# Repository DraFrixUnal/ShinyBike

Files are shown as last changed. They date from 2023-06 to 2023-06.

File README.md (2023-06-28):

# Shiny Bike

Dispositivo que busca iluminar y señalizar a las bicicletas.

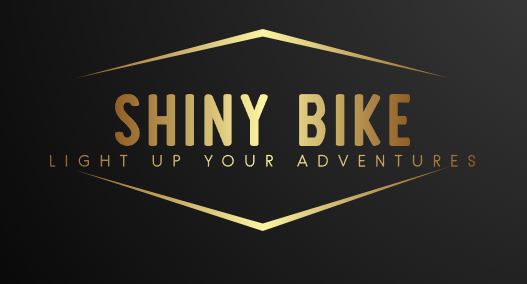
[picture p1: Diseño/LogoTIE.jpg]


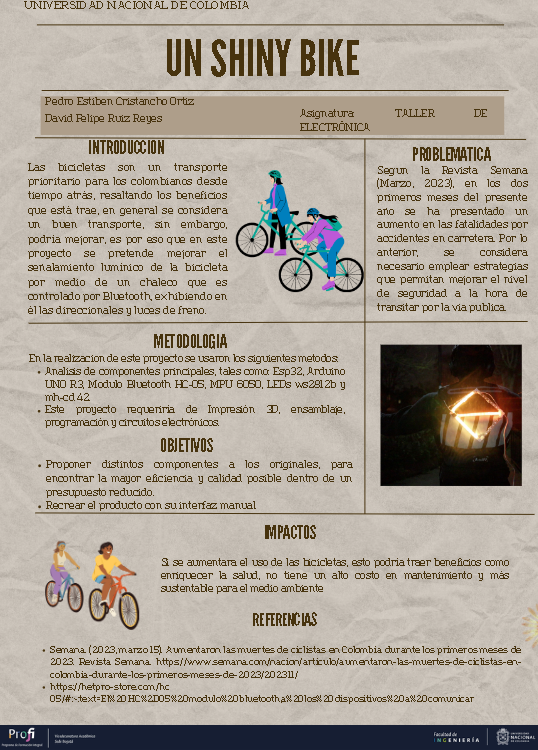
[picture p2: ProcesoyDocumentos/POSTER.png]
Poster


## Descripcion

Este dispositivo busca que los ciclistas puedan señalizar a traves de luces su recorrido en las calles (direccionales, frenado, parqueo). El dispositivo se divide en dos partes, la primera la cual es un control remoto permite al usuario emitir comandos manueales y comandos automaticos para el seña.amiento, segun que comando dicte se enviaran datos via Bluetooth a la segunda parte, la cual se encarga de iluminar los led RGB Ws2812b.

## Objetivos

- Desarrollar un dispositivo que sea capaz de iluminar y señalizar de forma remota a cualquier bicicleta.
- Desarrollar los esquematicos, PCB, diseños y codigos que permitan alcanzar el dispositivo y un buen aprendizaje

## Alcance

Todos los ciclistas que quieran iluminar sus aventuras en la calle.

## Planeación 

### Diagrama de Flujo

Aqui se establecio oficialmente las funciones y las interacciones del dispositivo.

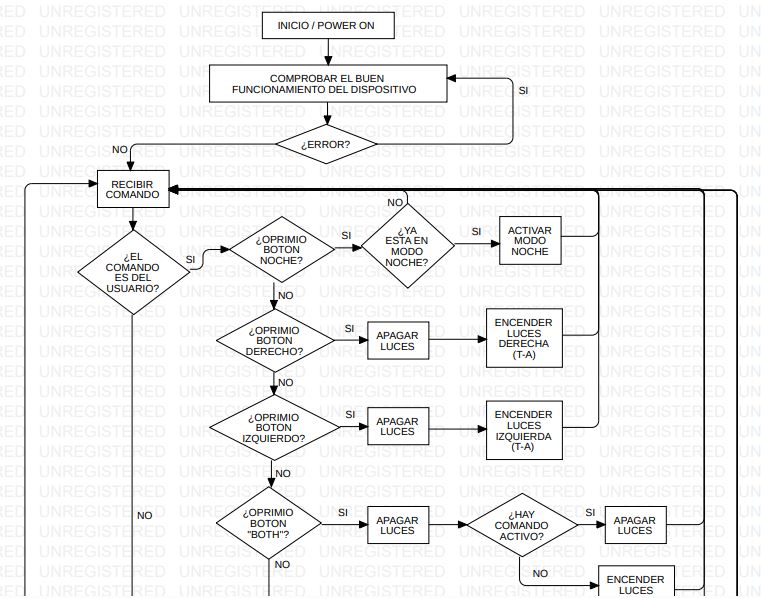
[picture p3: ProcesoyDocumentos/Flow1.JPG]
Flow1

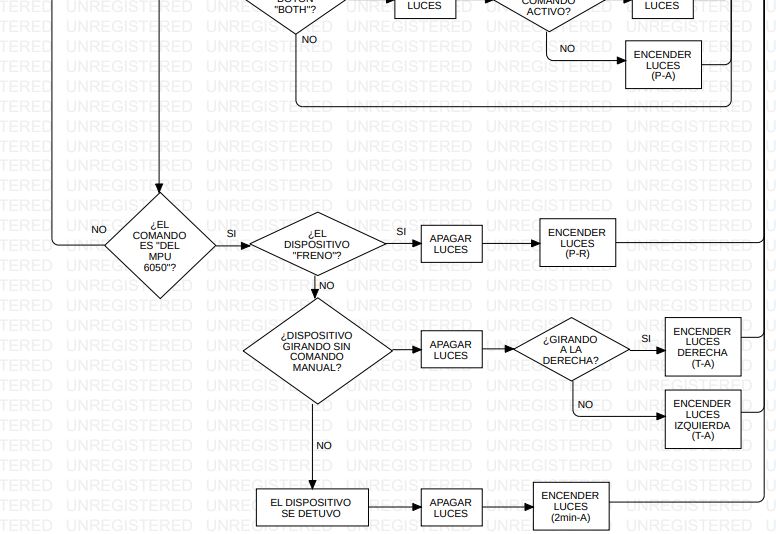
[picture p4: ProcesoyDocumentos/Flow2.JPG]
Flow2


### Diagrama de Cajas Negras

Aqui se establecieron las principales tecnologias.

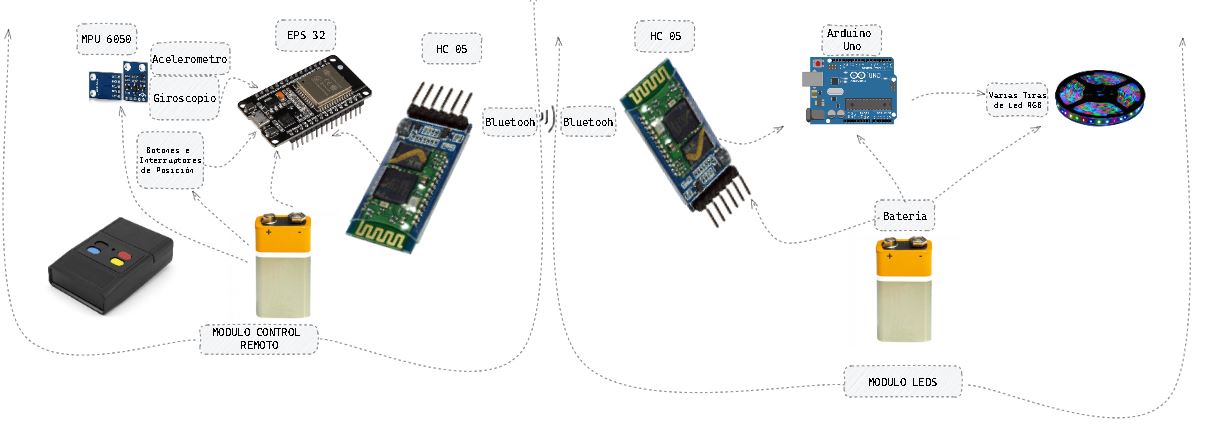
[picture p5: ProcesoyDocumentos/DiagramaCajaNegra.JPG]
DCN


# Diseño

En esta sección, se empieza diseñar y construir la parte electronica del dispositivo, con lo cual se diseñaron los esquematicos y las PCB.

## Esquematicos

Esquematico Control Remoto
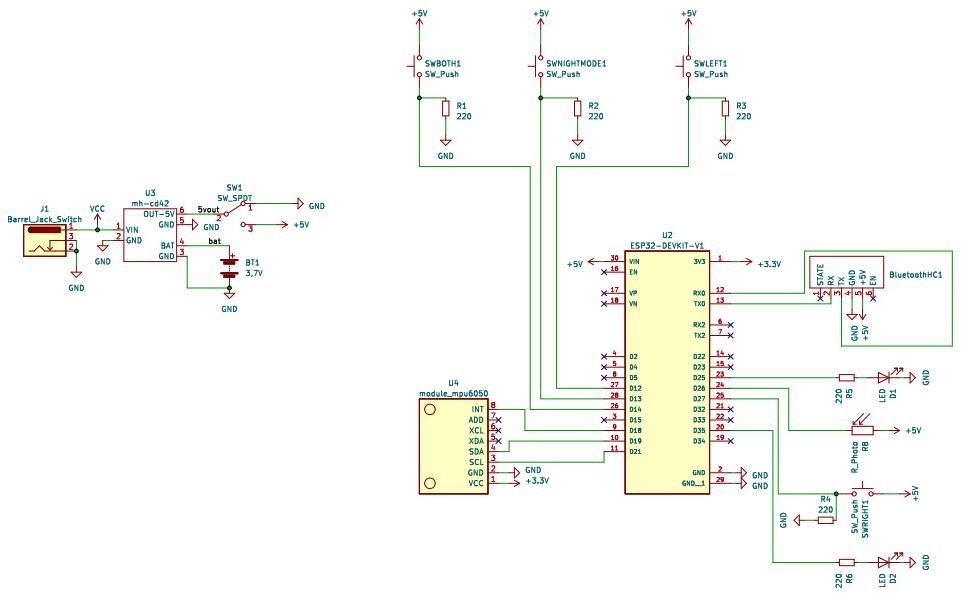
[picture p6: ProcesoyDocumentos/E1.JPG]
E1

Esquematico Luces
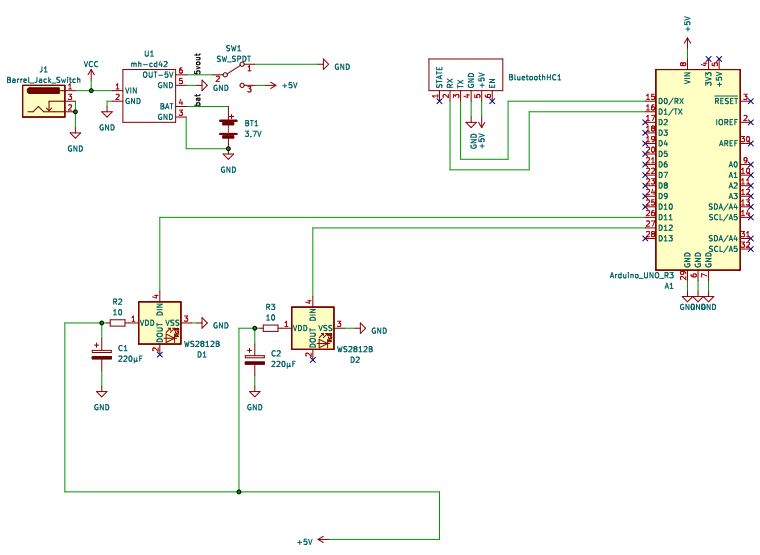
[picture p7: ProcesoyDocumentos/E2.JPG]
E2


## PCB

PCB del Control Remoto

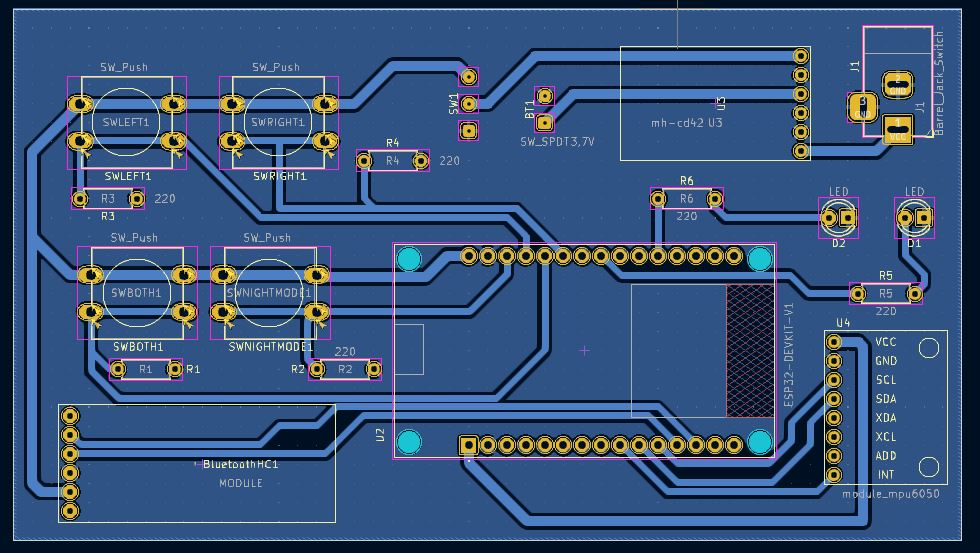
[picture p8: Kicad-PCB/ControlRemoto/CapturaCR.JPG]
PCB1

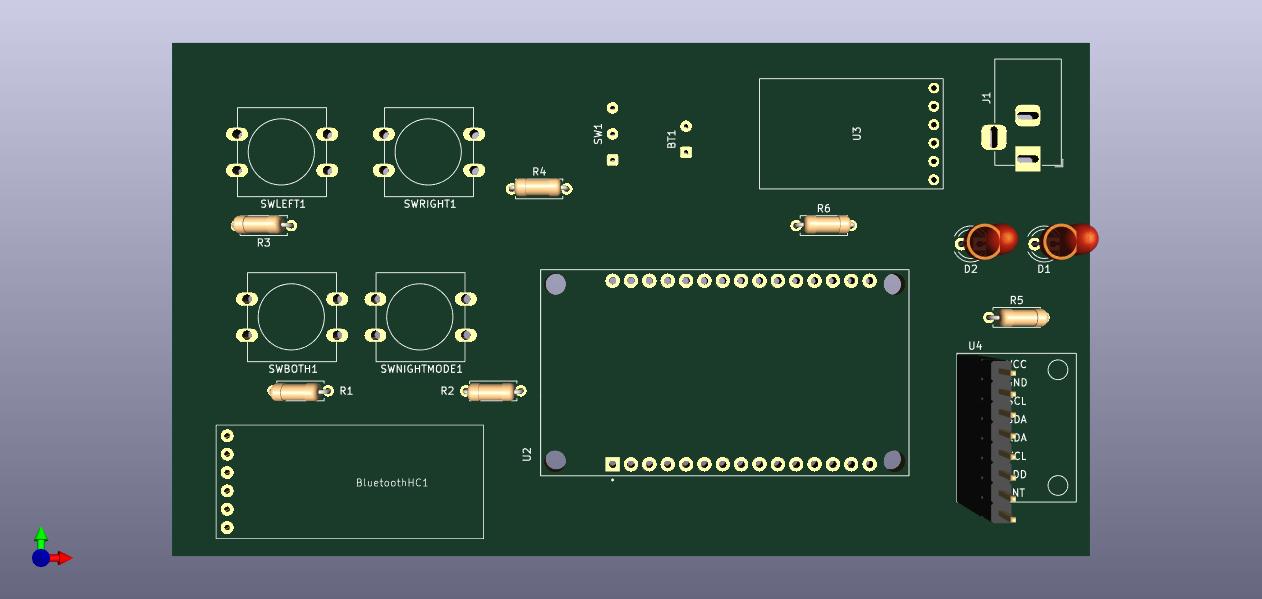
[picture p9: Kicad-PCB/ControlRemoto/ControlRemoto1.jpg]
PCB11

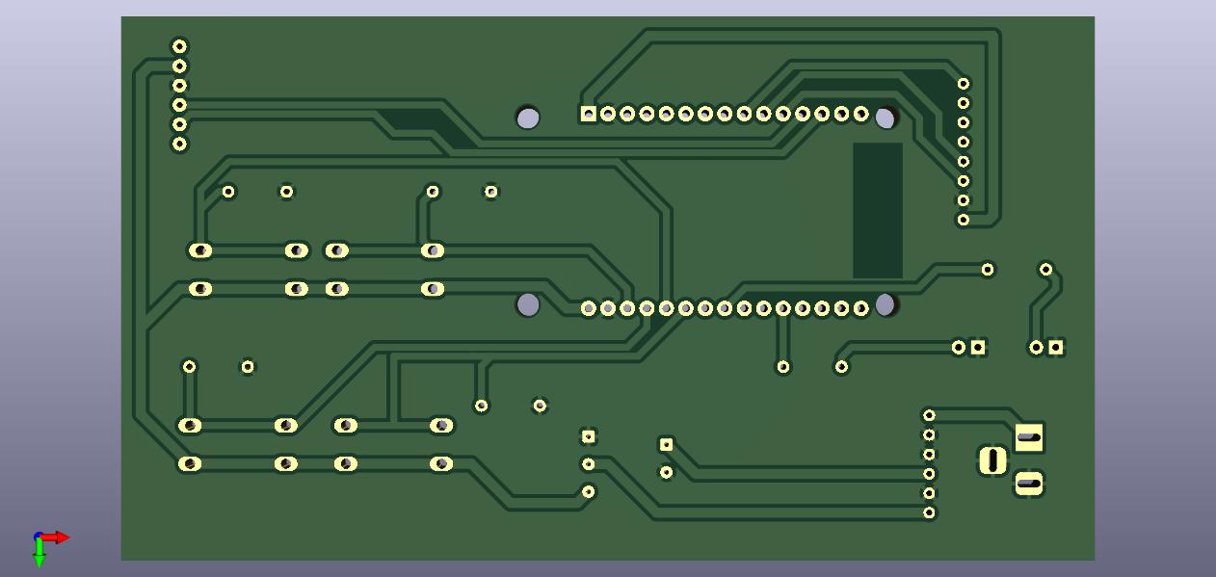
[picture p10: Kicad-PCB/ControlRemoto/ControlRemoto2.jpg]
PCB111


PCB de apartado de Luces

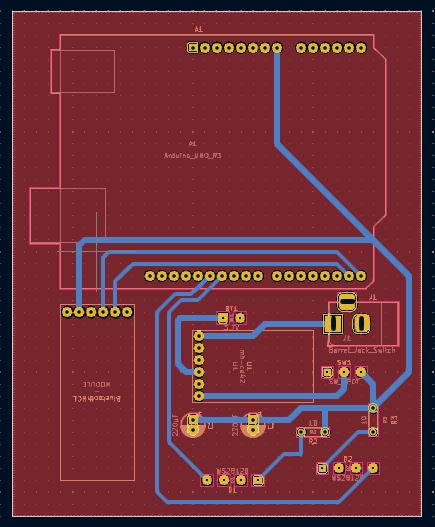
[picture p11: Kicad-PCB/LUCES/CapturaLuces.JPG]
PCB2

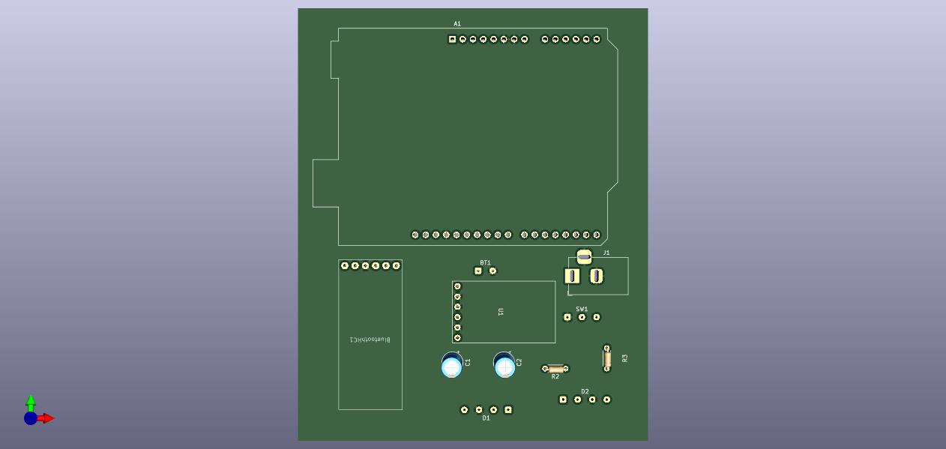
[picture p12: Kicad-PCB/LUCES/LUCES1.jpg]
PCB22

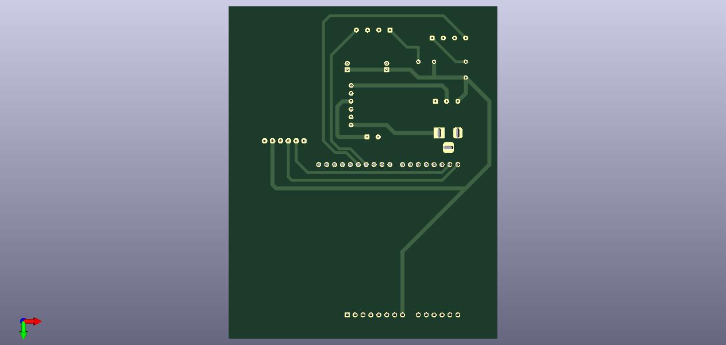
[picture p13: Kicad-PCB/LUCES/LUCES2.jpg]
PCB222


# Prueba y Trabajo hecho

Aqui se realizaron pruebas en ProtoBoard para corroborar el funcionamiento del codigo y construir el dispositivo final.

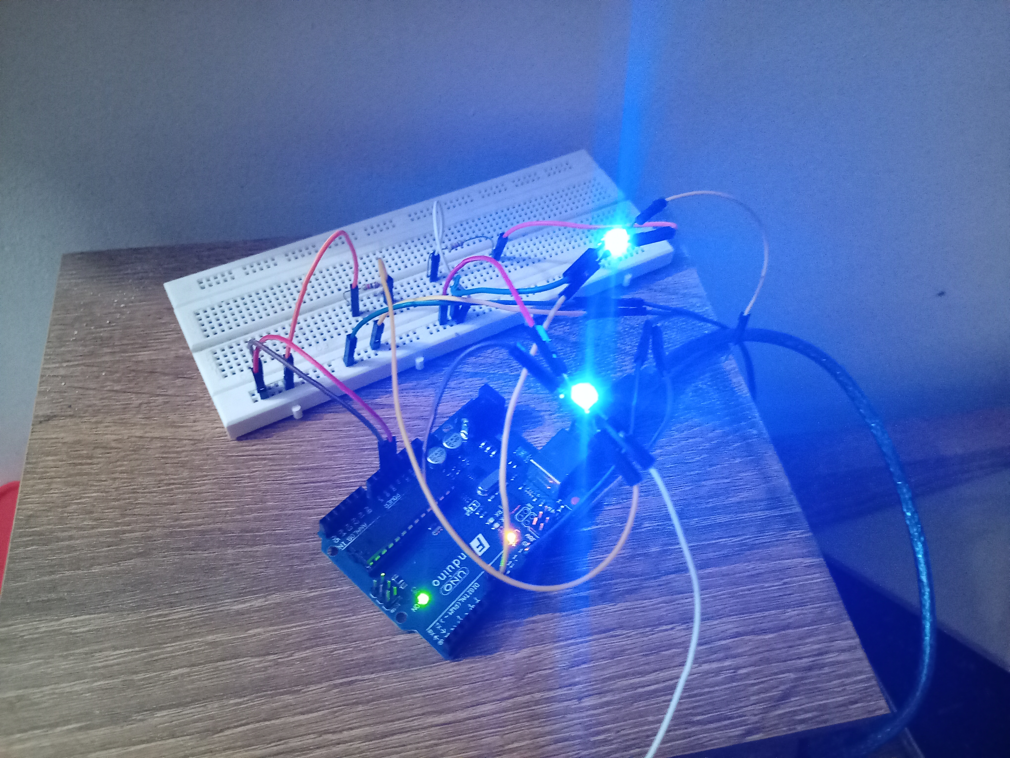
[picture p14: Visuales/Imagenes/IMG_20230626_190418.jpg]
T1


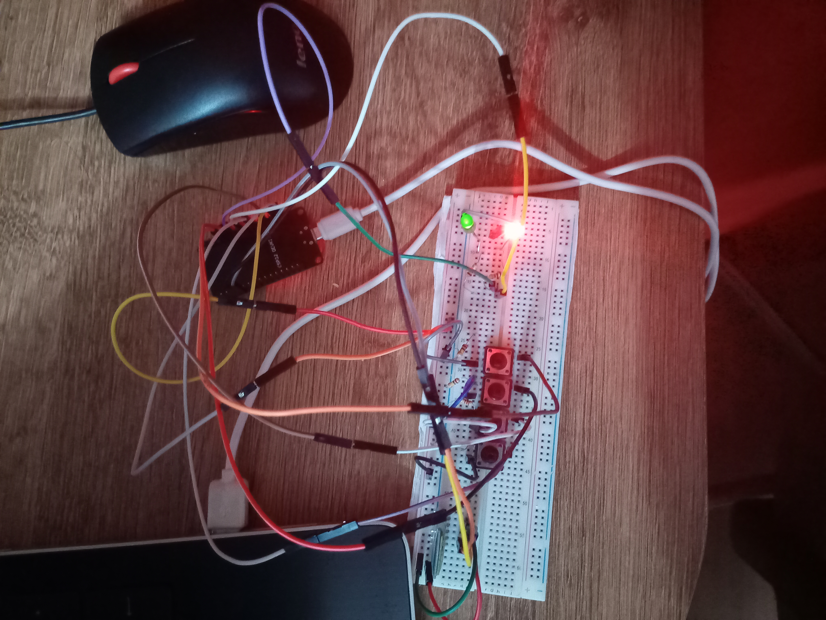
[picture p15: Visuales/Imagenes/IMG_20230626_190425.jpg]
T2


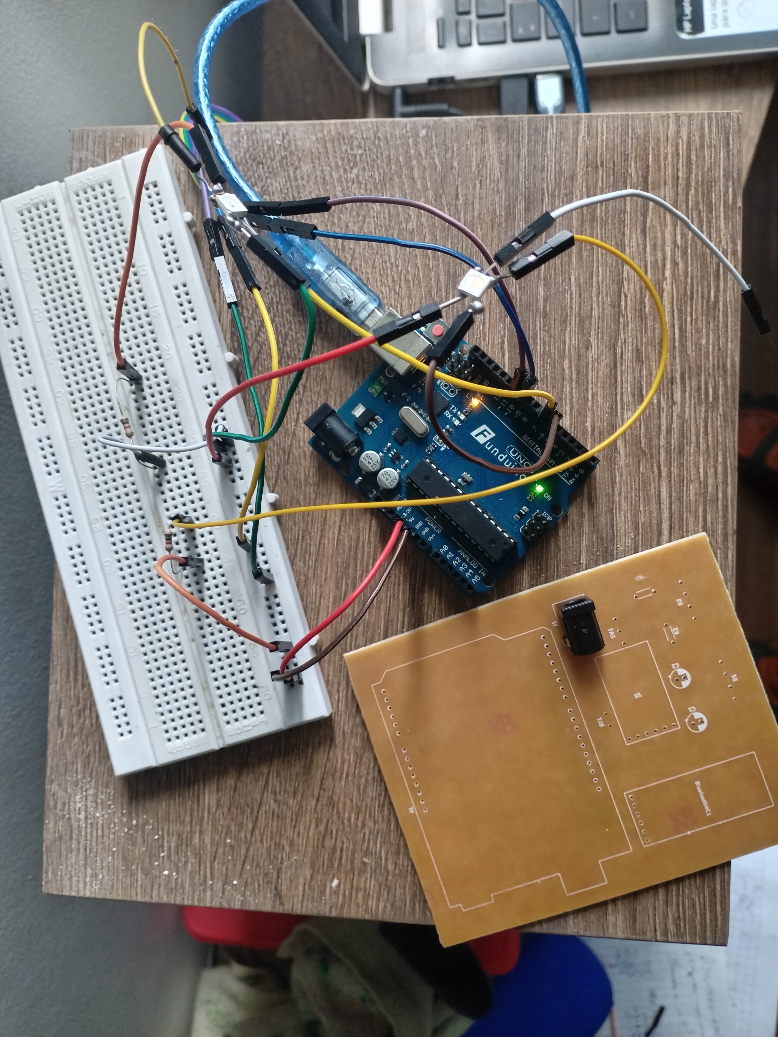
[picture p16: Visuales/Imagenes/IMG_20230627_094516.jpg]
T3


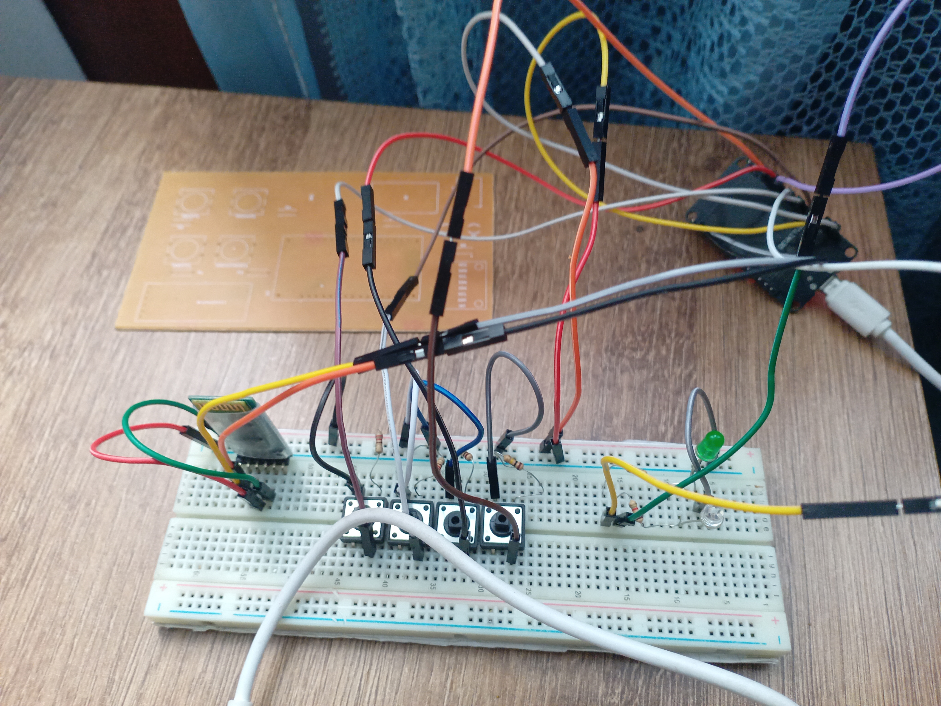
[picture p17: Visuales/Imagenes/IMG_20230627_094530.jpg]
T4


T5

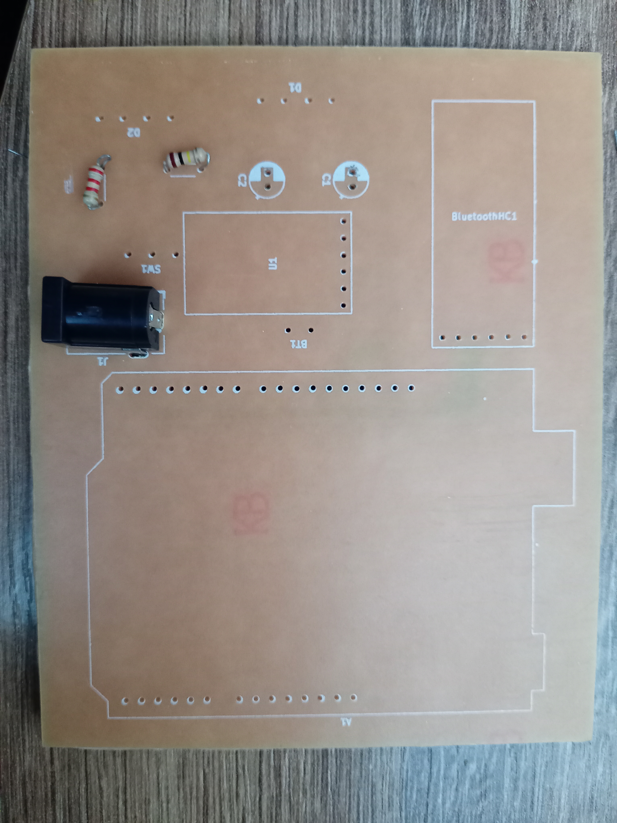
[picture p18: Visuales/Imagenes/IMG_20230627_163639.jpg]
T6


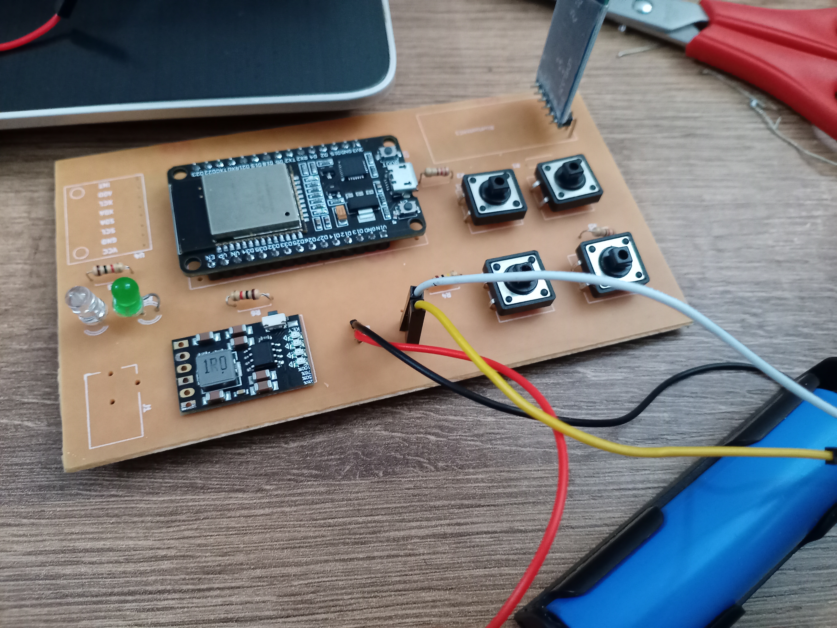
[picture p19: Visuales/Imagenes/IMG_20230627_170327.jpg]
T7


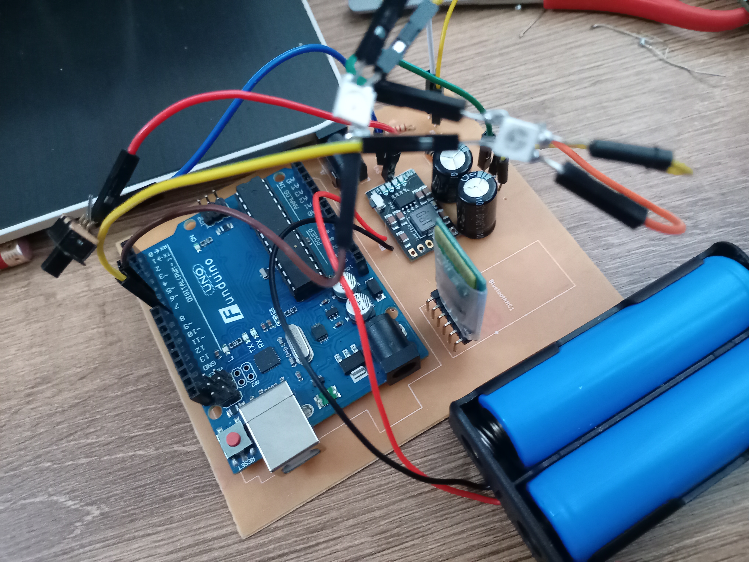
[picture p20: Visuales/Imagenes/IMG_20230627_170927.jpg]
T8


## Videos

Links de los videos:
 - Dispositivo funcionamiento [Vdf](https://youtu.be/l_CRdRnh4ok)
 - Explicacion Bluetooth [Veb](https://youtu.be/JUIpYABRpQY)
 - Videos de los problemas [Vp1](https://youtu.be/4-EyFK3v-QM),[Vp2](https://youtube.com/shorts/PcfQB73DB2A?feature=share),[Vp3](https://youtu.be/3R93eb1QBnk)

## Muchas gracias por su visita

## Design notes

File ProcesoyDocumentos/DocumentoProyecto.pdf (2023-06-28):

PROCESO DEL PROYECTO

DEFINICIÓN Y PLANEACIÓN DEL PROYECTO

Inicialmente nos planteamos tres alternativas, dos de estas eran de entretenimiento o decoración (característica que los descarto):

1. Un cubo de Leds RGB dinámicos y programables.
2. Un reloj de cartas - Calendario de cartas.
3. Dispositivo para dar señalamiento lumínico a las bicicletas.

Si estás aquí sabrás que escogimos la tercera opción y empezamos con la determinación de las funcionalidades. Para esto realmente se mantuvo una pequeña conversación ya que estas funcionalidades eran bastantes obvias, siendo las siguientes:

- Poner iluminar la dirección a tomar (derecha o izquierda).
- Poner señalar un próximo detenimiento o parqueo.
- Poder señalar el proceso de frenado.
- Cuando es de noche, se debe de tener iluminación permanente respetando las funcionalidades previas.

También por tema de presupuesto se dejo que las funcionalidades quedaran en “iluminación”, ya que el dispositivo como se mencionara posteriormente podría tener un sistema de sonido, un sistema que mida distancias o un sistema GPS.

Diagrama de Caja Negra

Ya con las funcionalidades establecidas se empezó a establecer la tecnología a utilizar. Para esto se utilizo el diagrama de caja negra el cual es muy intuitivo y dinámico, teniendo el siguiente resultado:

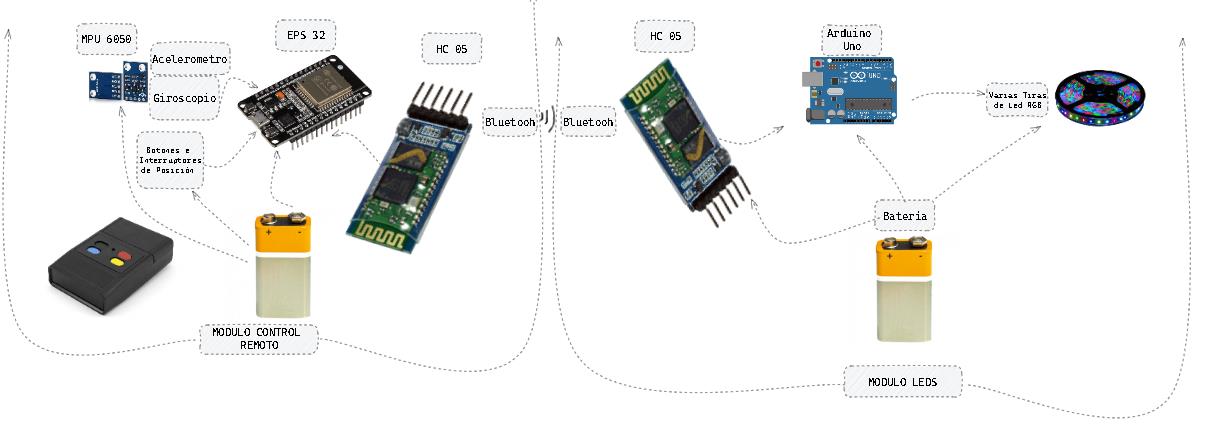
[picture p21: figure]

Este diagrama se divide en dos partes, la parte del Control Remoto y la parta de las Luces (De aquí en adelante cada parte se llamará correspondientemente a lo dicho).

El Control Remoto posee un esp32 DEVKIT DOIT v1 como cerebro, una batería (18650 de 3,7V) como alimentación, un MPU 6050 para automatizar algunas señales y el HC-05 para la conexión Bluetooth con Luces, el cual a su vez contiene un hc.05, un Arduino UNO como cerebro, dos baterías como alimentación y una conexión a las tiras LED de iluminación.

Ahora ampliando lo dicho, queremos empezar con la siguiente pregunta: ¿Por qué se escogieron estas tecnologías? Iniciemos por el HC-05, este dispositivo nos permite generar una conexión Bluetooth entre ellos y además nos permite controlar las direcciones entre los módulos, contraseñas, nombres, controlar si es un Maestro o Esclavo (Si es host o no), etc. Con esto conseguimos una conexión entre partes remotas de un mismo dispositivo de manera segura, rápida y confiable. Sobre el MPU 6050 es muy poco lo que toca mencionar en este documento, este dispositivo es muy versátil a la hora de medir alteraciones en la velocidad lineal y en la velocidad angular, siendo perfecto para medir los cambios que pueden presentarse a la hora de usar una bicicleta o cualquier vehículo (Se recomienda leer sobre este dispositivo en internet). Para escoger el esp32 y el Arduino fue mas complicado el camino ya que inicialmente teníamos que el MPU 6050 funciona mejor bajo 3,3V mientras que el resto de los circuitos trabajaban a 5V, se sumaba el hecho de necesitar trabajar en el lenguaje C++ para el manejo de librerías próximas a escoger, junto a la necesidad de escoger entre Wi-Fi y Bluetooth en la interconexión (el primer componente a escoger de cada parte fueron los cerebros), el pequeño espacio que debían tener la PCB fututas y el tema del presupuesto. Pero con una leve investigación el esp32 era la elección más acertada ya que cumplía todas las características e incluía las formas de interconexión mencionadas (se escogió Bluetooth por la economía del HC-05 y no se usó el propio del esp32 por temas de seguridad), ¿pero entonces, donde aparece en juego el Arduino? El Arduino aparece por la imposibilidad de conseguir el segundo esp32, ya que los envíos estaban ciertamente caros y el Arduino ya se tenía en posesión antes de iniciado el proyecto. La única desventaja que esto representa es el tamaño de la placa.

Sobre las tiras LED RGB, se escogieron los ws2812b, ya que presentaban una alta gama de colores, las librerías son sencillas de utilizar, algunas webs aseguraban que eran aprueba de agua e iluminan bastante. Por economía se compraron los LED en si y no las cintas, ya que nuevamente los envíos son excesivamente caros en Colombia (el metro de la cinta es barato en contraste). Por último, en la parte de alimentación tenemos a las baterías 18650 de 3,7V que se escogieron por ser tanto recargables como duraderos (el dispositivo puede pasar bastante tiempo sin cargar), para cargar dichas baterías se usaron puertos Jack y módulos MD-CH42 que permiten hacer el proceso de carga-descarga de baterías dando 5V constantes al circuito.

Diagrama de flujo – Costos

Invitamos a ver o descargar los archivos adjuntos a este proyecto, ya que lo que se mencionara aquí son mínimos detalles.

Sobre el diagrama de flujo cabe resaltar que existen funcionalidades prioritarias, como los es el frenado y por esto mismo en el flujo a la hora de existir una desaceleración todas las otras funciones quedan bloqueadas.

Sobre los costos se ha de resaltar que las compras fueron hibridas y que el presupuesto estaba alrededor de los $200.000

Con esto la planeación había acabado y entramos a la producción.

ESQUEMATICOS, CODIGO Y PCB

Para esta parte se usaron dos Software, KiCad para la creación de los esquemáticos y las PCB, y Arduino IDE para el código.

Empezando por lo esquemáticos, estos iniciaron con la búsqueda de las “imágenes” de cada componente para poder generar las conexiones, anotación y correcciones correspondientes. Este proceso fue el mas laborioso realmente, siendo sorprendente el hecho de que nos tocara hacer los esquemas para el HC-05 t el MPU-6050 por mano propia (usando KiCad), pero fue una experiencia valiosa. Al final se generaron los siguientes esquemáticos:

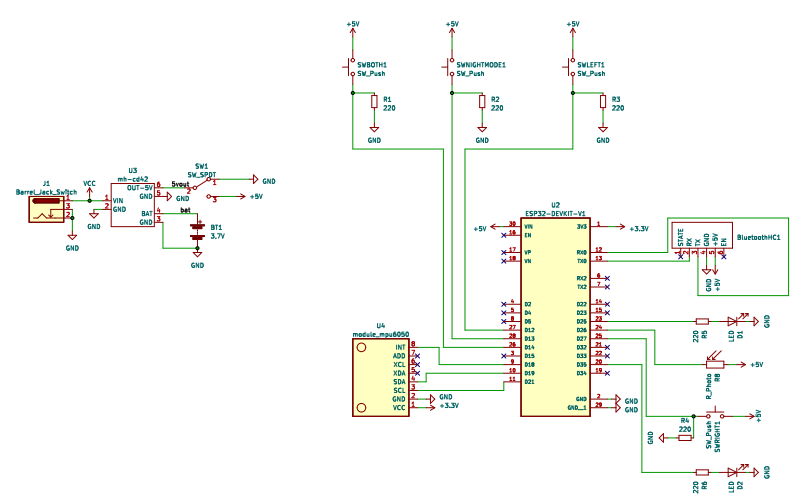
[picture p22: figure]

Esquemático Control Remoto

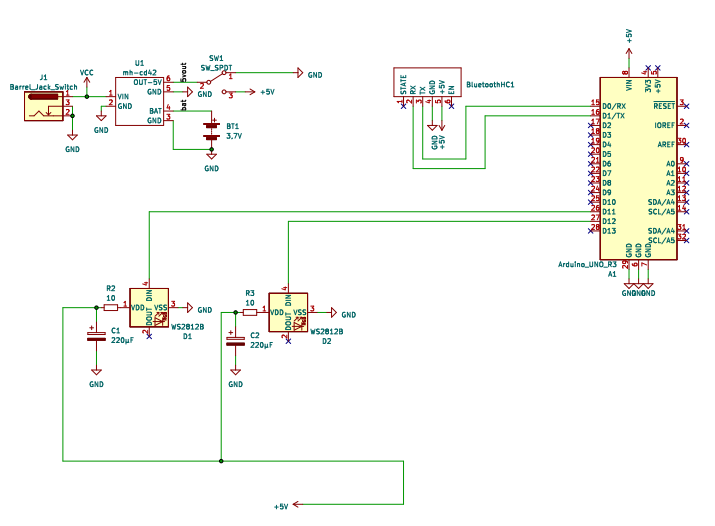
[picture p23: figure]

Esquemático Luces

Ya con los esquemáticos hechos asignamos las huellas (footprints) de cada componente, siendo para varias de ellas (como los ws2812b) simples “puntos de conexión”. Cabe aclarar que también toco realizar algunos footprints propios.

Después de esto seguía la creación de las dos PCB, pero como ya se tenía la mayoría hecho gracias a los esquemáticos, solo todo ordenar los componentes y realizar las conexiones (diferenciando los anchos de pista según el voltaje y la función de cada una, por ejemplo, las pistas de señal requieren menos grosor) y creando un campo GND. El resultado fue el siguiente:

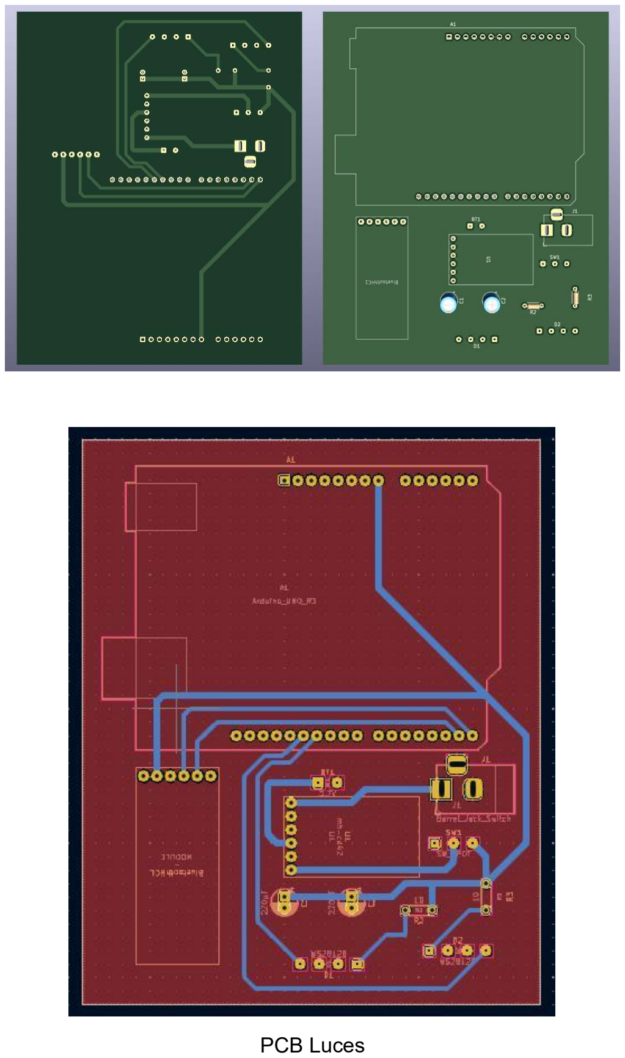
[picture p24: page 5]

PCB Luces

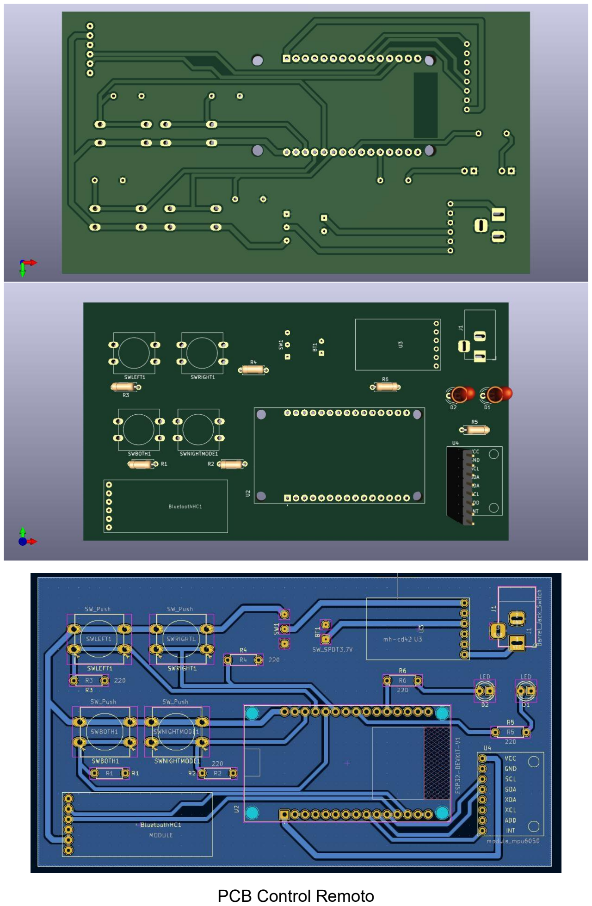
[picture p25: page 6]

PCB Control Remoto

Con todo listo se empezó el desarrollo del código. Primero cabe aclarar que la parte de decir que LED encendía o como se enviaba información a través del Serial se deja a disposición del lector, por lo sencillo que ha de ser el código. Por lo que solo hablaremos de lo importante.

Primero se configuraron lo HC-05, para estos se conectaron los módulos tanto al esp32 como al Arduino (igual que en el esquemático, pero mientras se conecta el 5V de los módulos se ha de oprimir el botón que estos poseen, así entran en modo de configuración) y se empezó una conexión con el Monitor Serial a 9600 baudios, después se inició la conexión con los módulos a 38400 baudios, permitiendo utilizar los comando AT. Estos comandos permiten conocer los datos de los HC-05 como el nombre o la contraseña y a su vez los permite cambiar. La ecuación es esta, para conocer un dato se colocar AT+(NAME o PSWD o MODE, etc) y si se desea cambiar se escribe el mismo comando un igual y el dato nuevo. Por lo que con esto hecho, se convirtió el HC de las Luces en esclavo (solo una conexión a un maestro) y el HC del Control en el maestro (Host), además se configuro que solo se pudieran conectar entre ellos (cambie el CMODE, el BIND o dirección y el PSWD de ambos). Para saber más de este proceso recomendamos investigar en internet. Y por último recordar, que cuando acaben de configurar escriban el comando AT+RESET y esos 38400 baudios del código los pasen a 9600, si no, al enviar datos de dispositivo a otro, lo que llegara será un carácter de pregunta o un carácter de cuadrado al no reconocer la información correctamente.

Sobre el control de los ws2812b se utilizó la librería Adrafruit_NeoPixel el cual permitía en tres líneas inicializar los leds: se asigna el strip, se inicializa y se muestra. Para cambiar el color únicamente se llamaba al strip, al numero del led y al color nuevo.

Sobre el MPU 6050 también recomendamos la lectura vía internet ya que de ahí se hizo un “copia y pega” y funciono preliminarmente.

Pruebas del Prototipo

Realizamos las pruebas en ProtoBoards para poder saber que todo funcionaba correctamente, y así fue a excepción de un problema que tuvimos con el MPU. Este modulo al soldar sus pines termino dañándose y fue imposible comprar su reemplazo, por lo que las pruebas fueron realizadas sin él.

Se recomienda ver los videos de demostración.

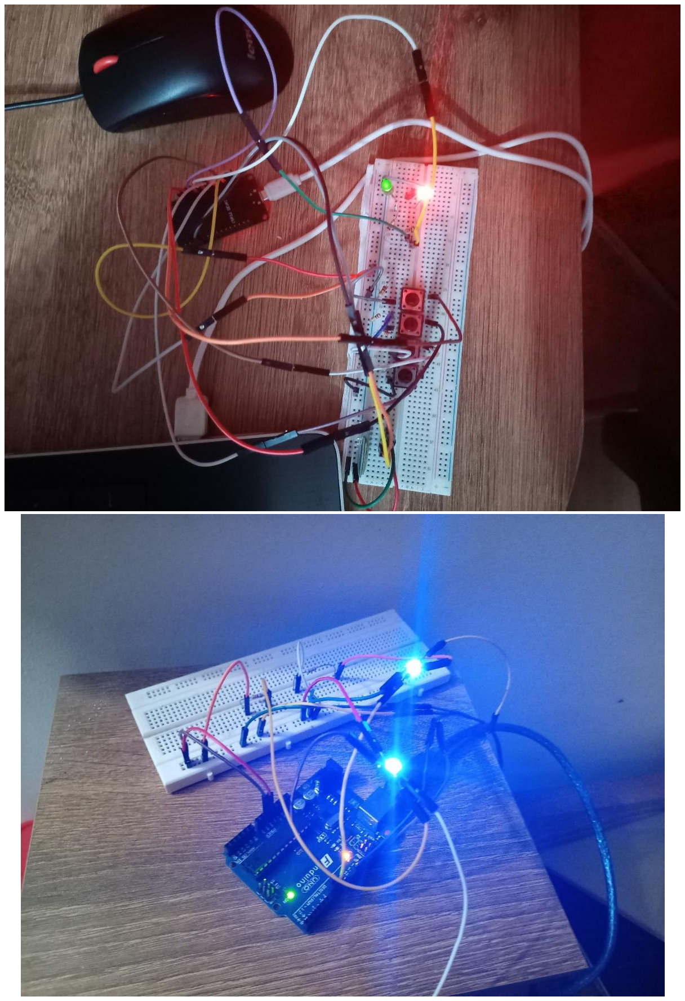
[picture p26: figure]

Imágenes al Atardecer

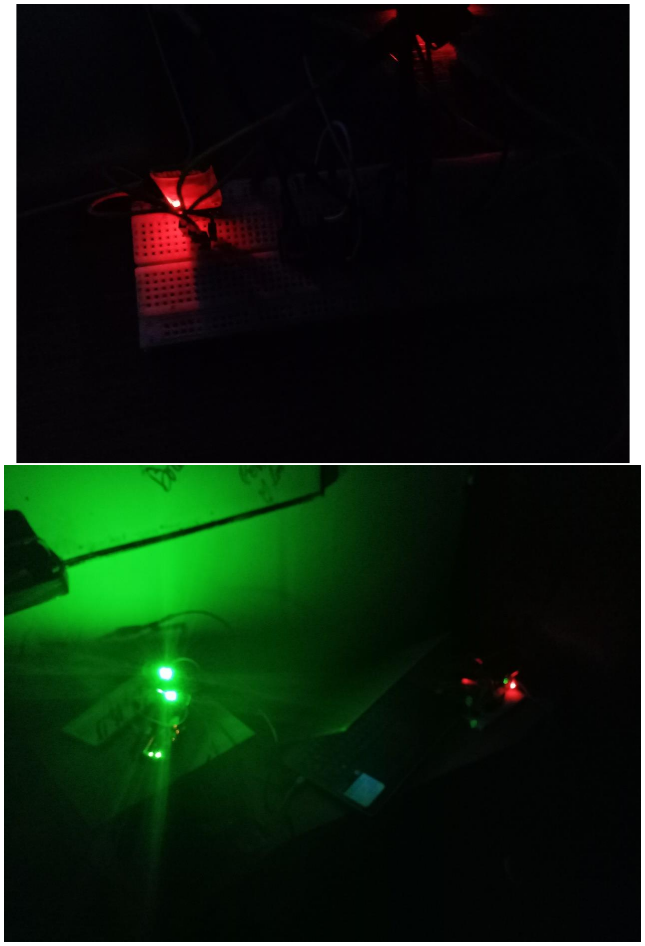
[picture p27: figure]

Imágenes en la Noche

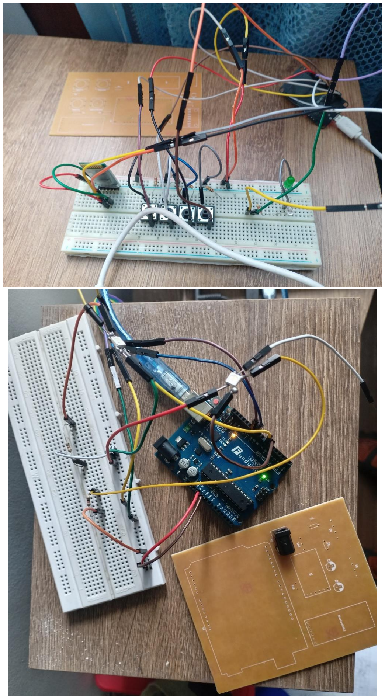
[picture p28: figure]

Imágenes en otra vista y con mas iluminación.

RESULTADOS FINALES

Primero quiero mostrarles los PCB.

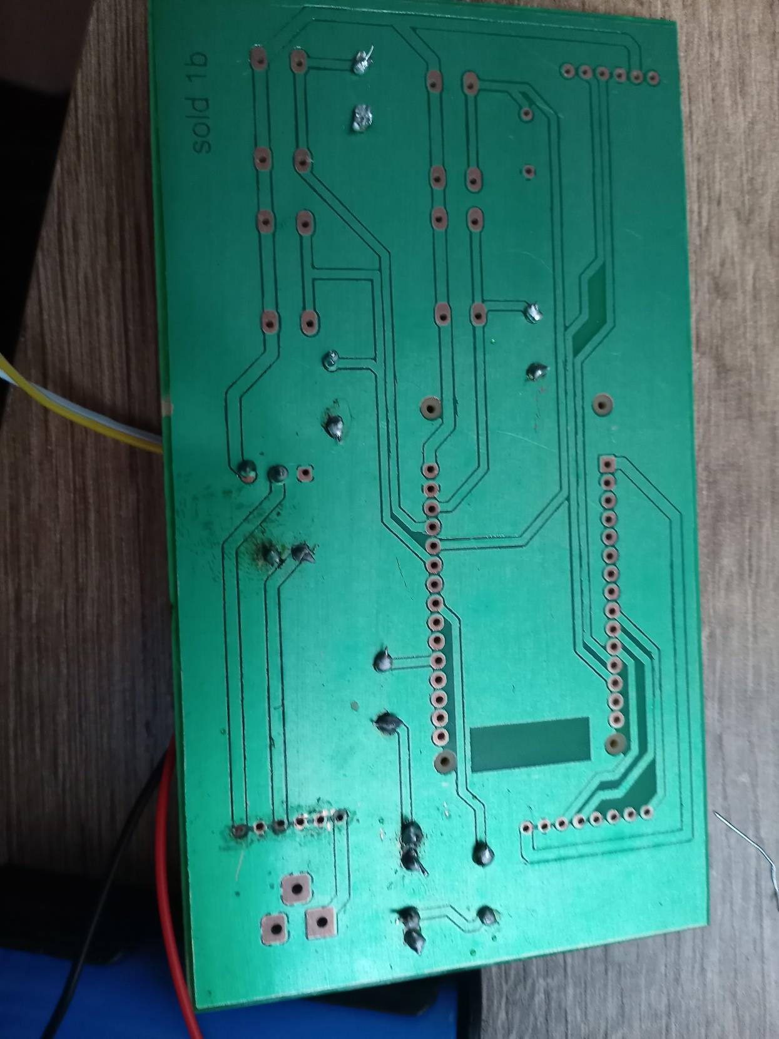
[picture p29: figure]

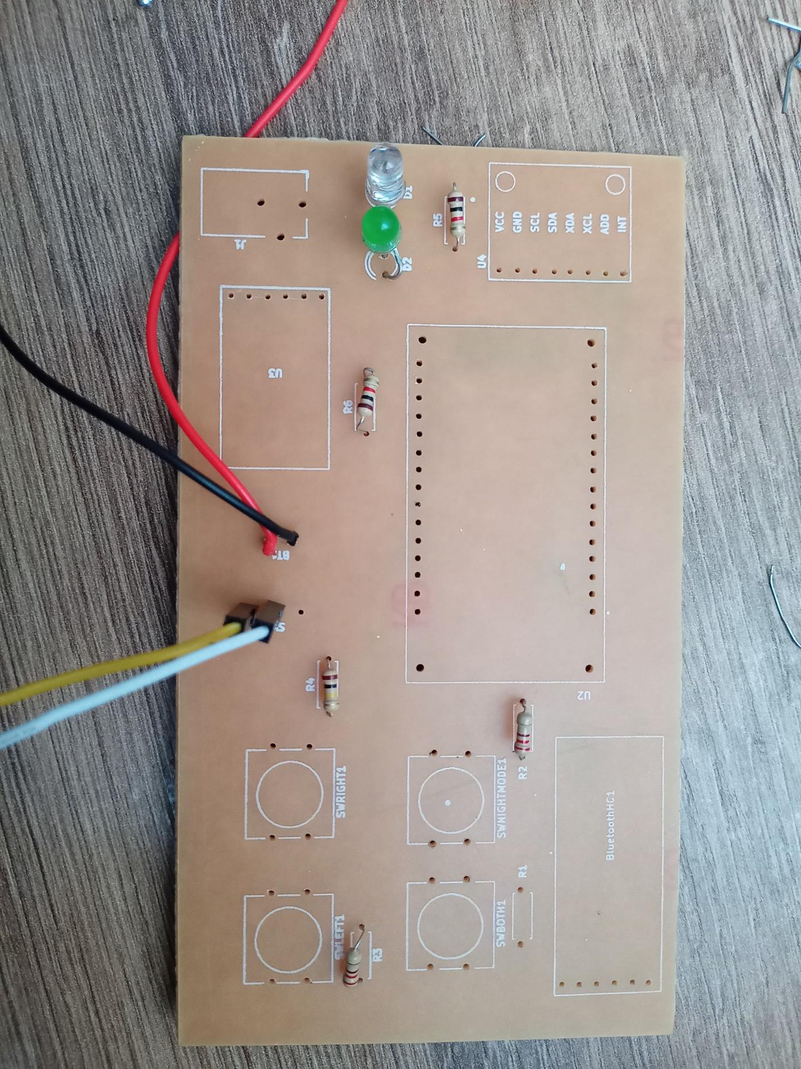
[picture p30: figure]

PCB Control Remoto

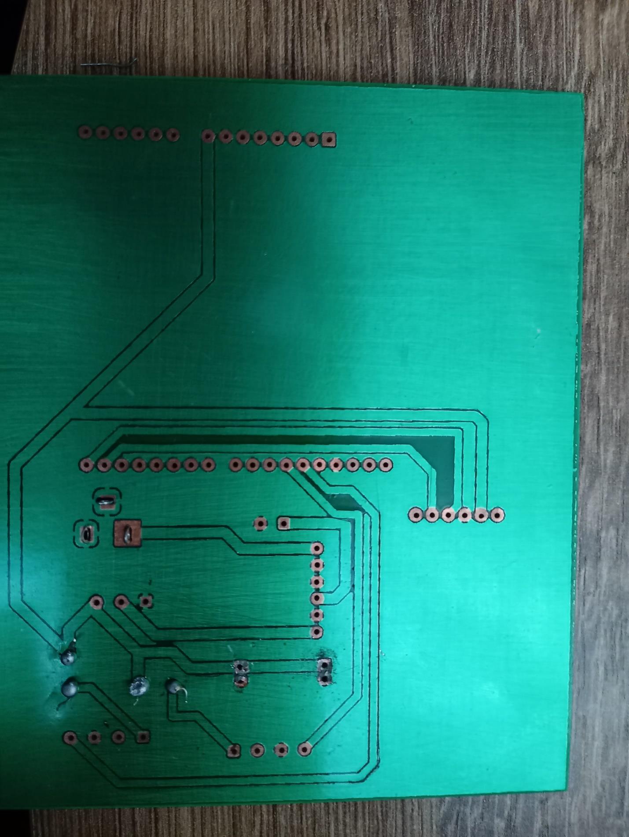
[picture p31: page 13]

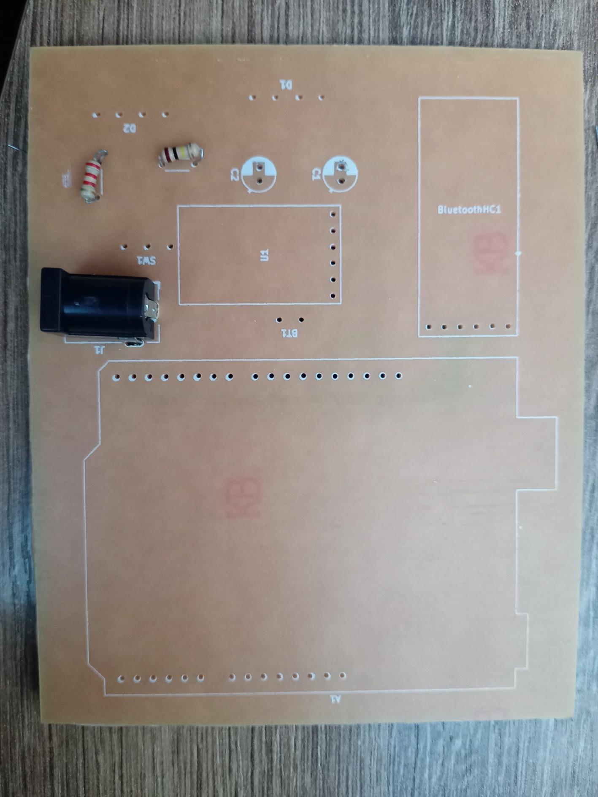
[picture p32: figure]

PCB Luces

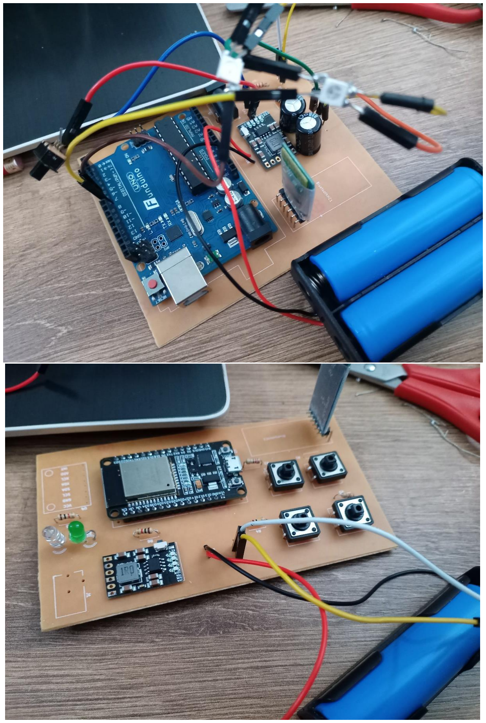
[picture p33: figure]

Visualización de como quedan conectadas

Como se puede ver, las PCB quedaron bastante estéticas y el dispositivo se ve bastante bien. Pero, lastimosamente las PCB no funcionaron, el ¿Por qué? Esta en la siguiente sección.

PROBLEMAS

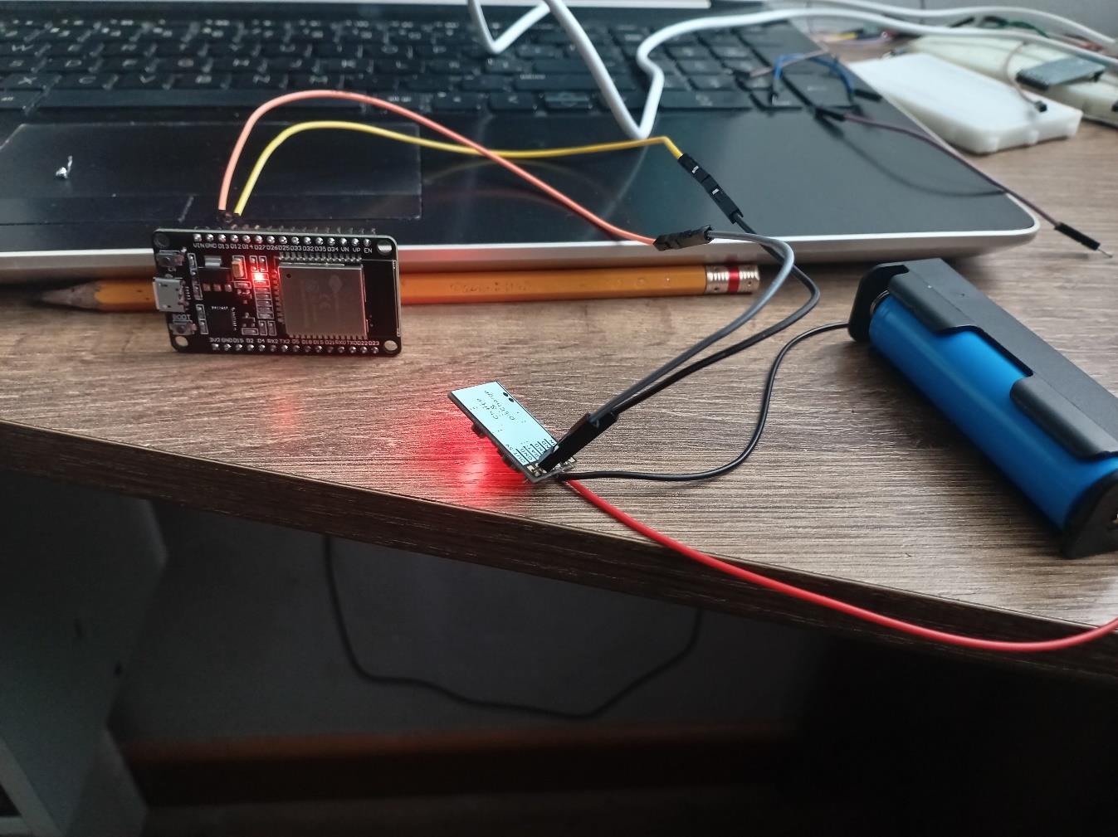
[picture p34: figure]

Imagen de pruebas del MH-CD42

Al conectar la PCB de Control remoto nos dimos cuenta de que algo malo estaba pasando, ya que ningún del rojo que indicara “encendidos” estaba alumbrando. Primero, tomamos un milímetro y medimos voltaje del interruptor al esp32 y nada, ceros. Después intentamos medir voltaje entre el Campo de GND de la placa y las primeras vías de alimentación (+5V, las de la batería, las del MH, etc), pero todas daban cero. Por lo que llegamos a dos hipótesis, o la PCB estaba dañada y no conducía o el MH estaba dañado (esta ultima ya era una pequeña muestra de esperanza ante la frustración). Como se ve en la imagen hicimos múltiples pruebas para la porta pilas, para el MH, y en todas funcionaban si no tocaban la PCB, por lo cual la primera hipótesis estaba casi corroborada. Por último, decidimos hacer pruebas en la PCB únicamente con los componentes de alimentación, colocando exceso de estaño, probando con Jumpers, etc. Pero nada funciono, la única manera de prender el MH era de forma directa como se debe ver en un video. También cabe aclarar que los MH no vieron en perfecto estado, pero aun así fueron lo suficientemente útiles para determinar el problema.

Lastimosamente en estas pruebas, el esp32 se vio afectado y ahora este, aunque prende, los pines digitales y los pines Tx y Rx se dañaron, enviando señales o datos siempre, con lo cual la placa quedo inútil.

Así que, lastimosamente por la calidad de la PCB y/o la calidad de nuestras soldaduras terminaron por acabar todo en la recta final. Por lo cual, invitamos a todos los lectores a revisar y mejorar este proyecto, ya que este dispositivo tiene alta utilidad y podría ayudarnos a nosotros también, ya que, aunque haya llegado el deadline del proyecto, nosotros seguiremos mejorándolo.

A FUTURO

- Como fue por aprendizaje, usamos placas completas, pero esto ocupa mucho espacio, con lo cual, en un futuro de ser posible, quisiéramos implementar solo el chip del esp32 ya programado para el proyecto
- Ampliar la escala tecnológica del proyecto, ya que como nos enfocamos en solo las luces, no alcanzamos a explorar las posibilidades del ultrasonido, la temperatura, el sonido y demás utilidades que la electrónica otorga. Mejorar y profesionalizando el proyecto.
- Conseguir una PCB y el MPU para corroborar que lo hecho estaba bien hecho, o en su contrario encontrar alternativas que evitar los problemas mencionados.

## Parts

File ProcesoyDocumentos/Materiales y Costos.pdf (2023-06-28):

# | Componente | Referencia | Cantidad | Precio Unidad

0 | Tarjeta de Desarrollo esp32 | Esp32 devkit doit | 1 | $ 41.000
1 | Tiras LED programables | Ws2812b | 1 o varios mts | $ 30.000
2 | Tiras LED programables | Ws2812b | 1 o varios mts | $ 30.000
3 | LED programable | Ws2812b | 6 / Usamos solo 2 (Al ser tan pequeños es recomendable comprar varios) | $ 5.000
4 | Modulo Bluetooth | Hc-05 | 2 | $ 28.000
5 | Portabaterias | 18650 | 2 | $ 6.000
6 | Baterias | 18650 | 3 | $ 25.000
7 | Cargador de Baterias | MH-CD42 | 2 | $ 6.000
8 | Acelerometro-Giroscopio | MPU6050 | 1 | $ 12.500
9 | Otros | $ 70.000 | CONDENSADORES,CABLES, PULSADORES,INTERRUPTORES,RESISTENCIAS,LEDS Y HERRAMIENTAS

Estos objetos o ya se tienen o seran utilizados según como avance el proyecto Si se hacen cuentas, el presupuesto de $200.000 fue muy
| superado

Link | Estado | Notas
| Adquirido
| Por adquirir | Aunque venga del mismo proveedor estamos seleccionando cual es mejor.
| Por adquirir
| Adquirido
| Adquirido | Pueda que se necesiten mas, pero con dos es suficiente según la fuente original
https://www.sigmaelectronica.net/ | Adquirido | Ya se tienen tanto para <5v y 9v como en el original. Permitiendo trabajar en esp32 o arduino
https://www.sigmaelectronica.net/ | Adquirido
https://www.sigmaelectronica.net/ | Adquirido
https://articulo.mercadolibre.com.co/MCO-630266839-giroscopio-acelerometro-mpu6050- | Adquirido

_JM#position=1&search_layout=stack&type=i (https://articulo.mercadolibre.com.co/MCO-630266839-giroscopio-acelerometro-mpu6050-_JM)

CONDENSADORES,CABLES, PULSADORES,INTERRUPTORES,RESISTENCIAS,LEDS Y HERRAMIENTAS

Estos objetos o ya se tienen o seran utilizados según como avance el proyecto

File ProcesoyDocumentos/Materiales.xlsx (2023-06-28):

# | Componente | Referencia | Cantidad | Precio Unidad | Link | Estado | Notas
0 | Tarjeta de Desarrollo esp32 | Esp32 devkit doit | 1 | $41000 | https://articulo.mercadolibre.com.co/MCO-654436748-tarjeta-de-desarrollo-esp32-wroom-32u-_JM | Adquirido
1 | Tiras LED programables | Ws2812b | 1 o varios mts | $30000 | https://articulo.mercadolibre.com.co/MCO-1174356614-metro-cinta-led-pixel-ws2812b-5v-60-led-negro-inteligente-_JM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 | Por adquirir | Aunque venga del mismo proveedor estamos seleccionando cual es mejor.
2 | Tiras LED programables | Ws2812b | 1 o varios mts | $30000 | https://articulo.mercadolibre.com.co/MCO-568322283-1-mt-cinta-led-pixel-ws2812b-5v-60-led-inteligente-1-led-rgb-_JM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 | Por adquirir
3 | LED programable | Ws2812b | 6 / Usamos solo 2 (Al ser tan pequeños es recomendable comprar varios) | $5000 | https://articulo.mercadolibre.com.co/MCO-571374986-1-metro-cinta-led-pixel-ws2812b-5v-inteligente-rgb-30-led-_JM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 | Adquirido
4 | Modulo Bluetooth | Hc-05 | 2 | $28000 | https://articulo.mercadolibre.com.co/MCO-453583096-sensor-infrarrojo-reflectivo-tcrt5000-seguidor-de-linea-_JM | Adquirido | Pueda que se necesiten mas, pero con dos es suficiente según la fuente original
5 | Portabaterias | 18650 | 2 | $6000 | https://www.sigmaelectronica.net/ | Adquirido | Ya se tienen tanto para <5v y 9v como en el original. Permitiendo trabajar en esp32 o arduino
6 | Baterias | 18650 | 3 | $25000 | https://www.sigmaelectronica.net/ | Adquirido
7 | Cargador de Baterias | MH-CD42 | 2 | $6000 | https://www.sigmaelectronica.net/ | Adquirido
8 | Acelerometro-Giroscopio | MPU6050 | 1 | $12500 | https://articulo.mercadolibre.com.co/MCO-630266839-giroscopio-acelerometro-mpu6050-_JM | Adquirido
9 | Otros | $70000 | CONDENSADORES,CABLES, PULSADORES,INTERRUPTORES,RESISTENCIAS,LEDS Y HERRAMIENTAS
Si se hacen cuentas, el presupuesto de $200.000 fue muy superado |  |  | Estos objetos o ya se tienen o seran utilizados según como avance el proyecto

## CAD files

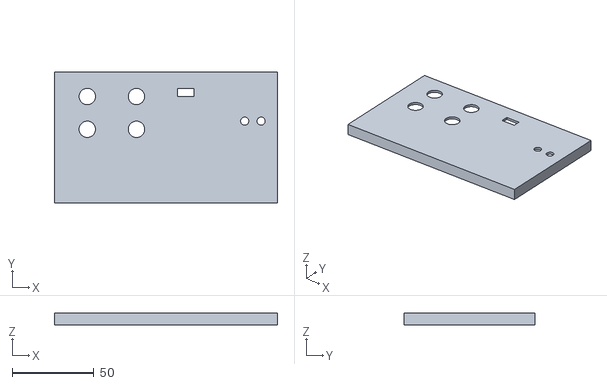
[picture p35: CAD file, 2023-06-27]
Diseño/TapaControl v1.stl
136.0 x 80.0 x 7.50

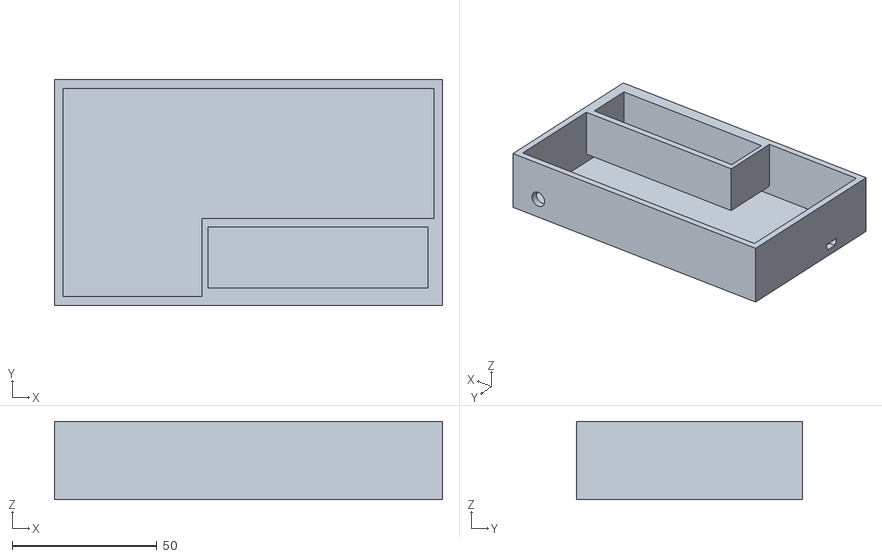
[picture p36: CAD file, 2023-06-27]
Diseño/Control v2.stl
134.0 x 78.0 x 27.0

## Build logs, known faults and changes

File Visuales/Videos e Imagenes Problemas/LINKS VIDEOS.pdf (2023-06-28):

LINKS VIDEOS

- Funcionamiento: https://youtu.be/l_CRdRnh4ok
- Exp. Bluetooth: https://youtu.be/JUIpYABRpQY

LINKS VIDEOS PROBLEMAS

- Vp1: https://youtu.be/4-EyFK3v-QM
- Vp2: https://youtube.com/shorts/PcfQB73DB2A?feature=share
- Vp3: https://youtu.be/3R93eb1QBnk

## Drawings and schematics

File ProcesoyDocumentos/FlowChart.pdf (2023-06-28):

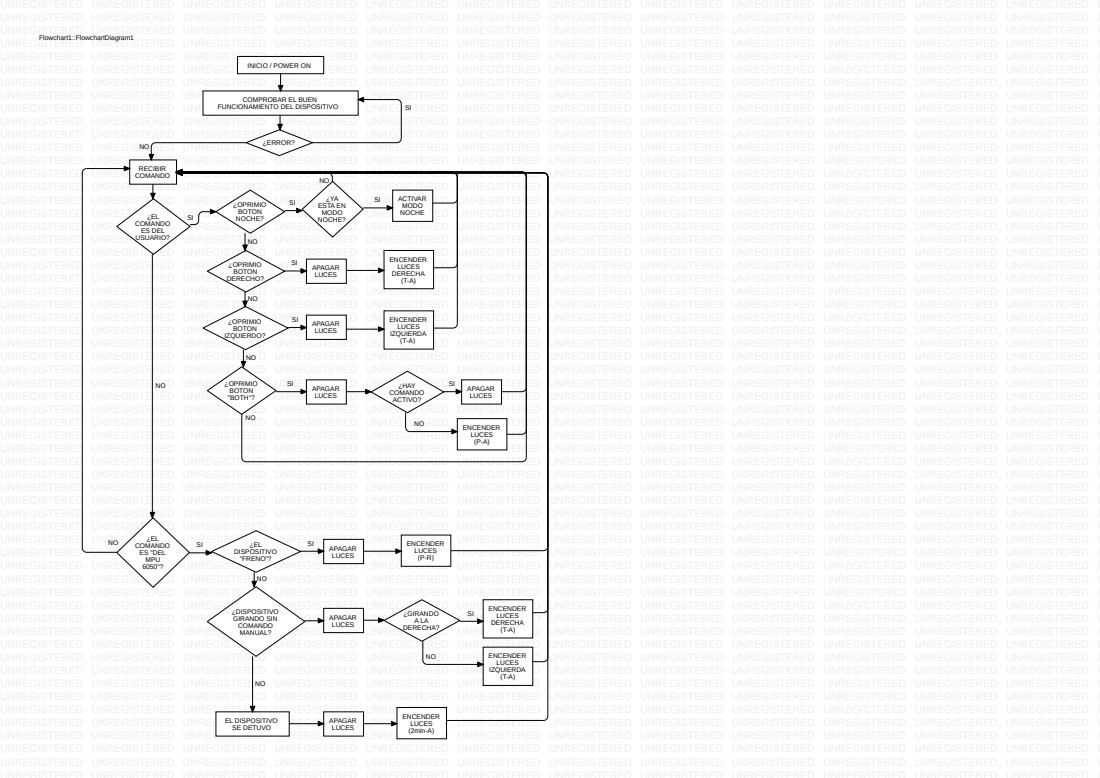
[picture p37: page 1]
UNREGISTERED UNREGISTERED UNREGISTERED UNREGISTERED UNREGISTERED UNREGISTERED UNREGISTERED UNREGISTERED UNREGISTERED UNREGISTERED UNREGISTERED UNREGISTERED UNREGISTERED UNREGISTERED UNREGISTERED UNREGISTERED UNREGISTERED UNREGISTERED UNREGISTERED UNREGISTERED UNREGISTERED UNREGISTERED UNREGISTERED UNREGISTERED UNREGISTERED UNREGISTERED UNREGISTERED UNREGISTERED UNREGISTERED UNREGISTERED UNREGISTERED UNREGISTERED UNREGISTERED UNREGISTERED UNREGISTERED UNREGISTERED UNREGISTERED UNREGISTERED UNRE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

INICIO / POWER ON

COMPROBAR EL BUEN

FUNCIONAMIENTO DEL DISPOSITIVO

ESTA EN MODO

ES DEL USUARIO?

ES "DEL MPU

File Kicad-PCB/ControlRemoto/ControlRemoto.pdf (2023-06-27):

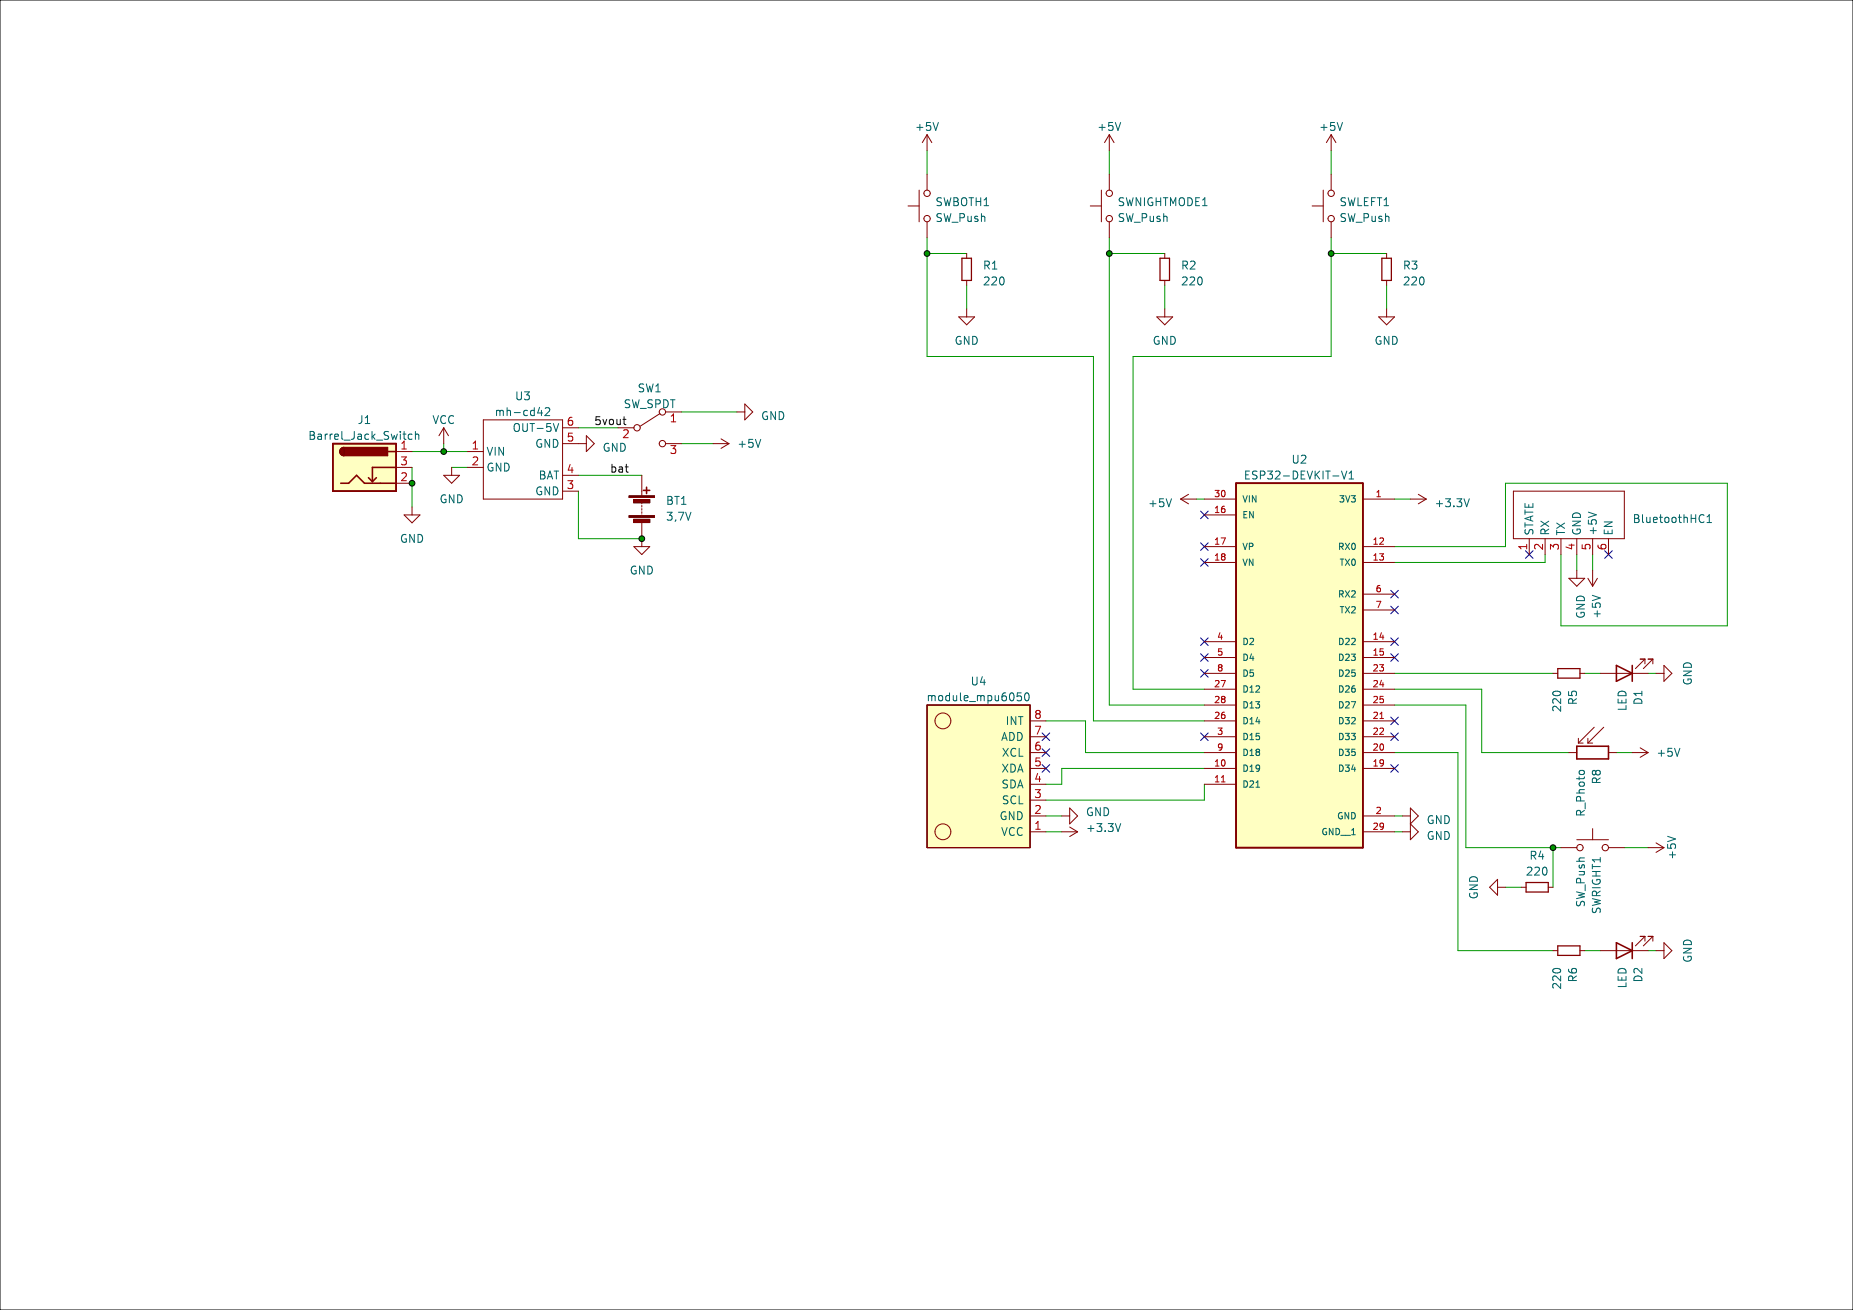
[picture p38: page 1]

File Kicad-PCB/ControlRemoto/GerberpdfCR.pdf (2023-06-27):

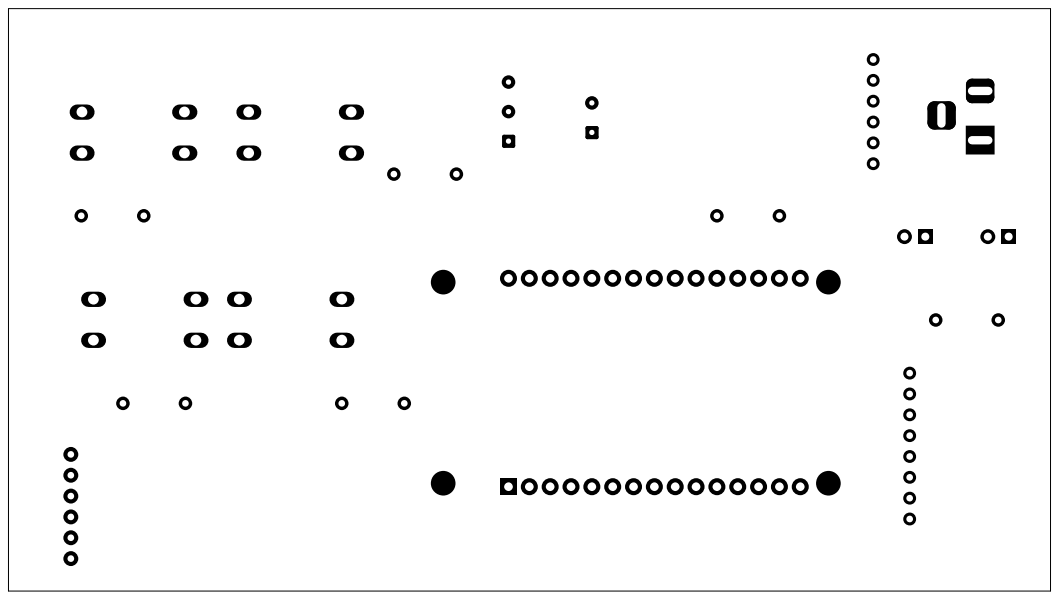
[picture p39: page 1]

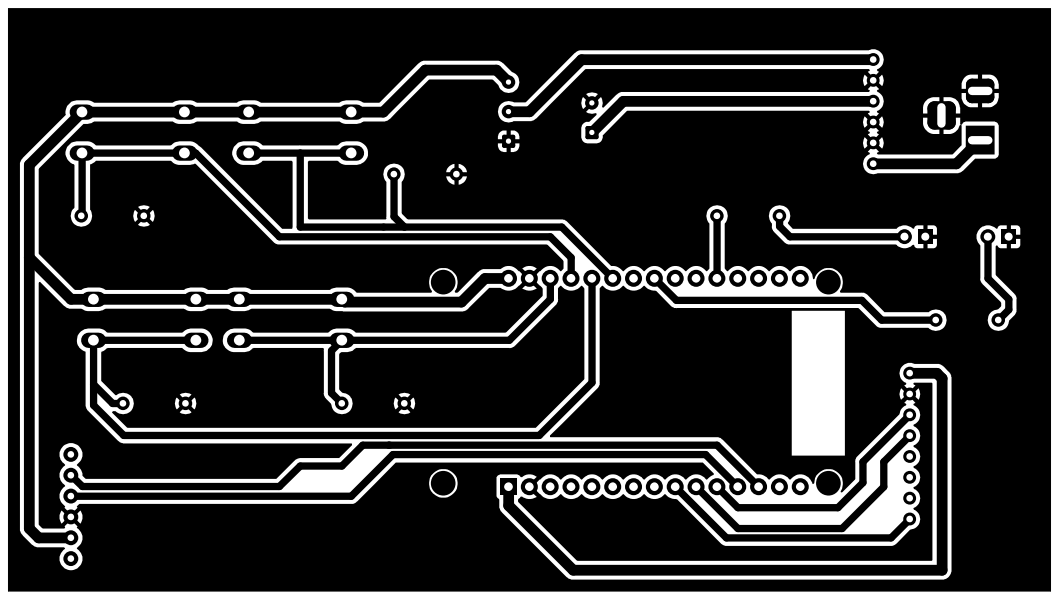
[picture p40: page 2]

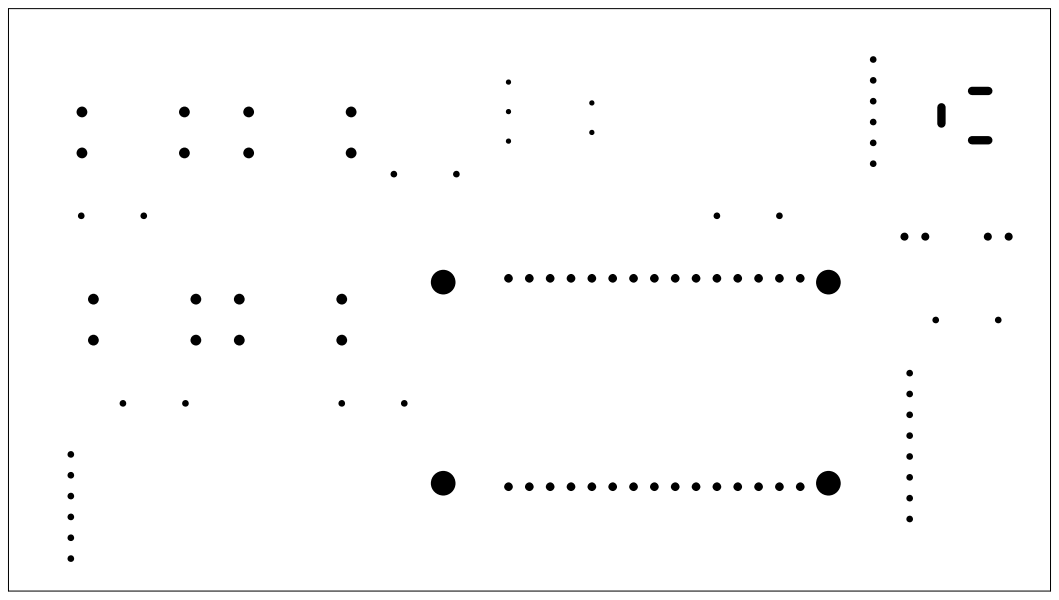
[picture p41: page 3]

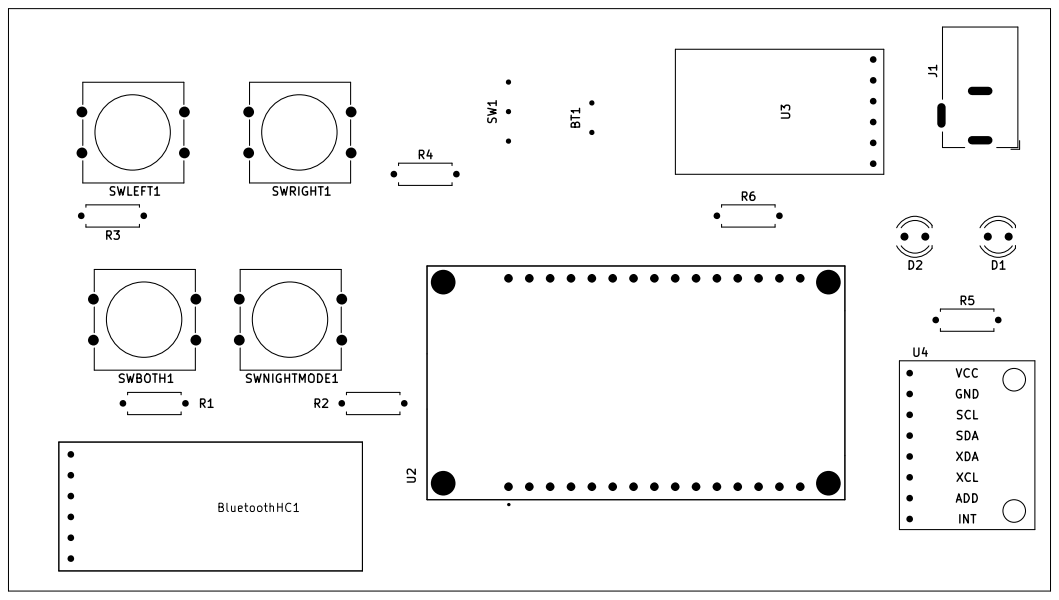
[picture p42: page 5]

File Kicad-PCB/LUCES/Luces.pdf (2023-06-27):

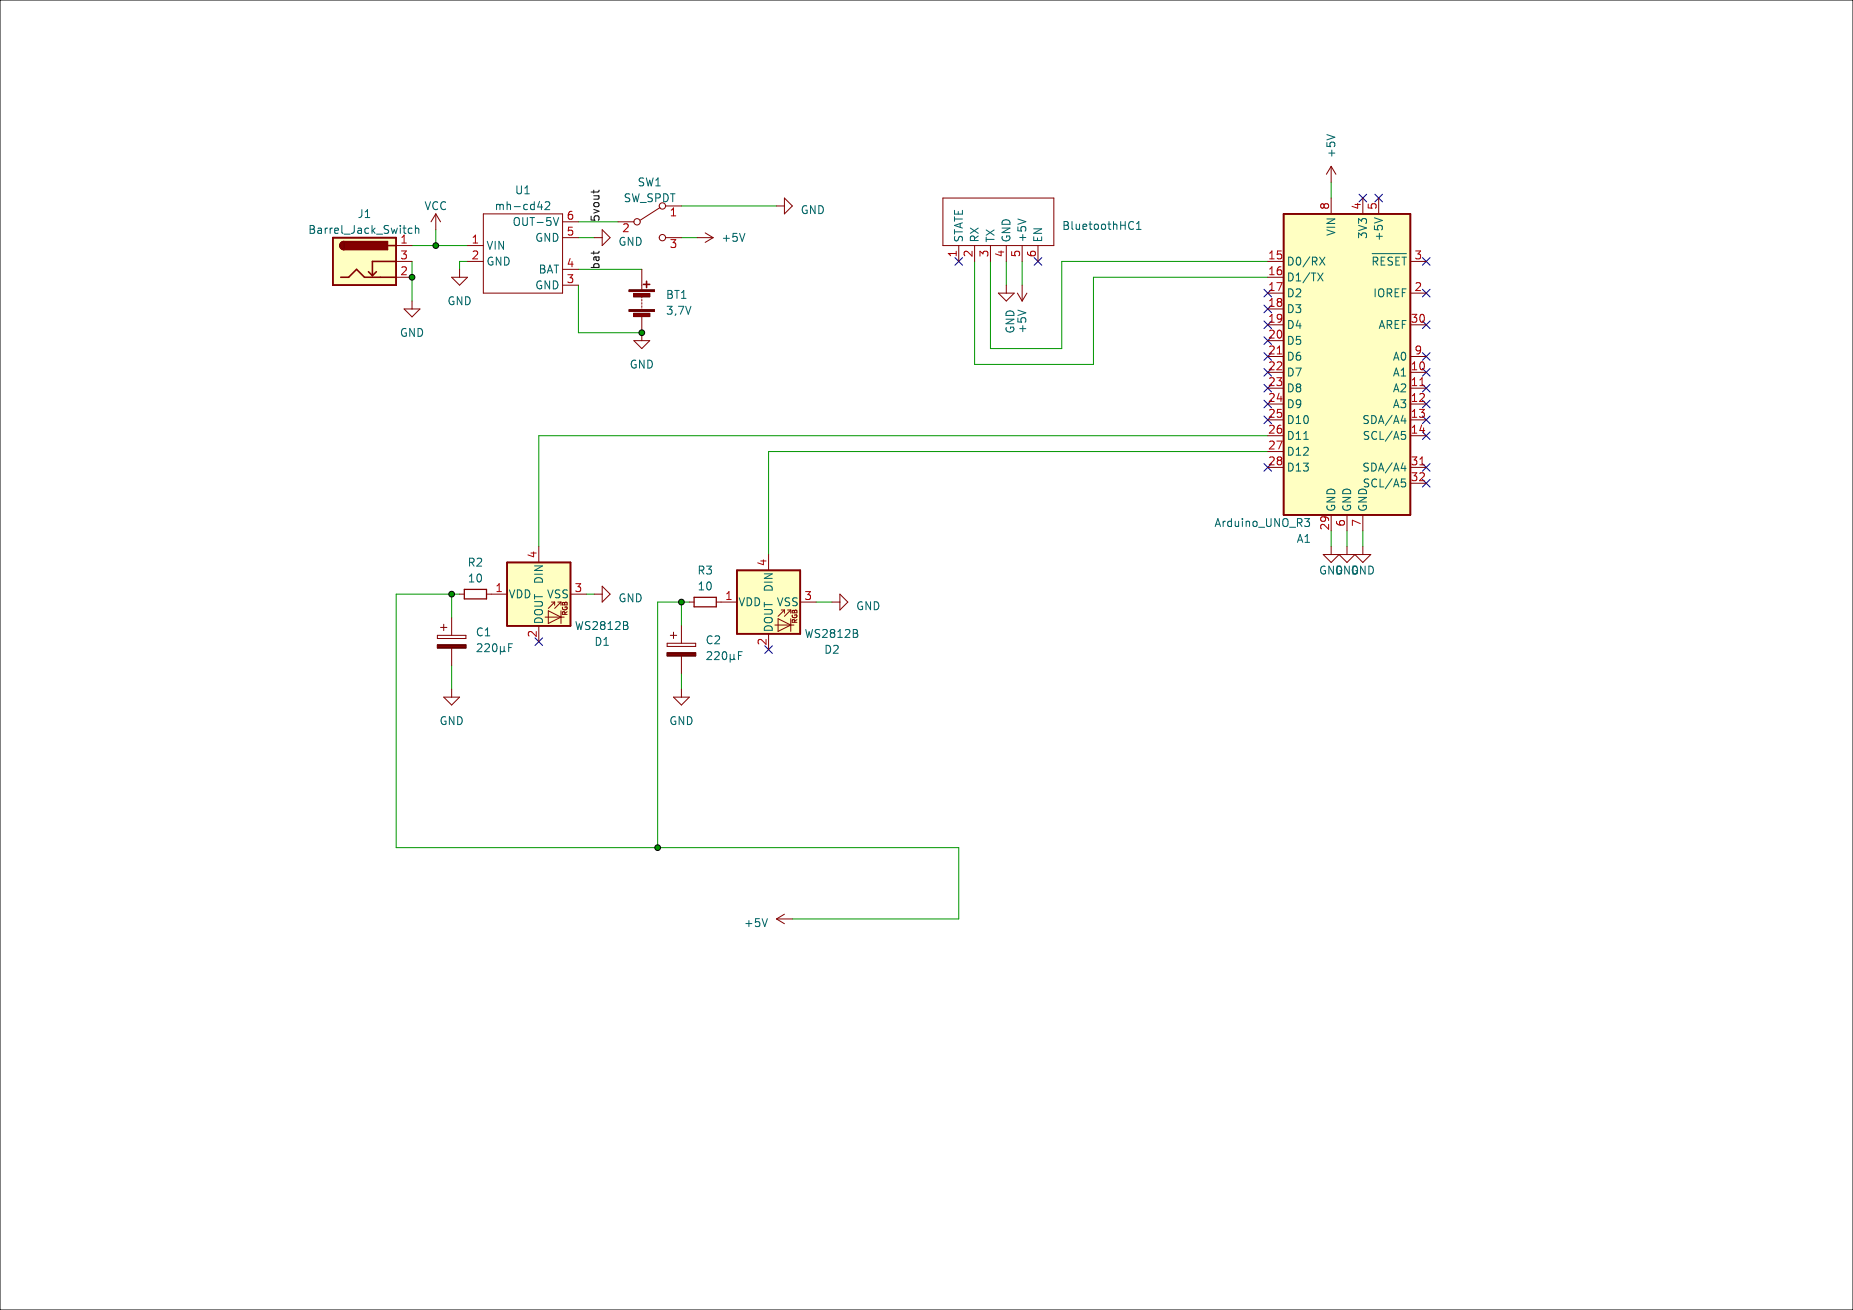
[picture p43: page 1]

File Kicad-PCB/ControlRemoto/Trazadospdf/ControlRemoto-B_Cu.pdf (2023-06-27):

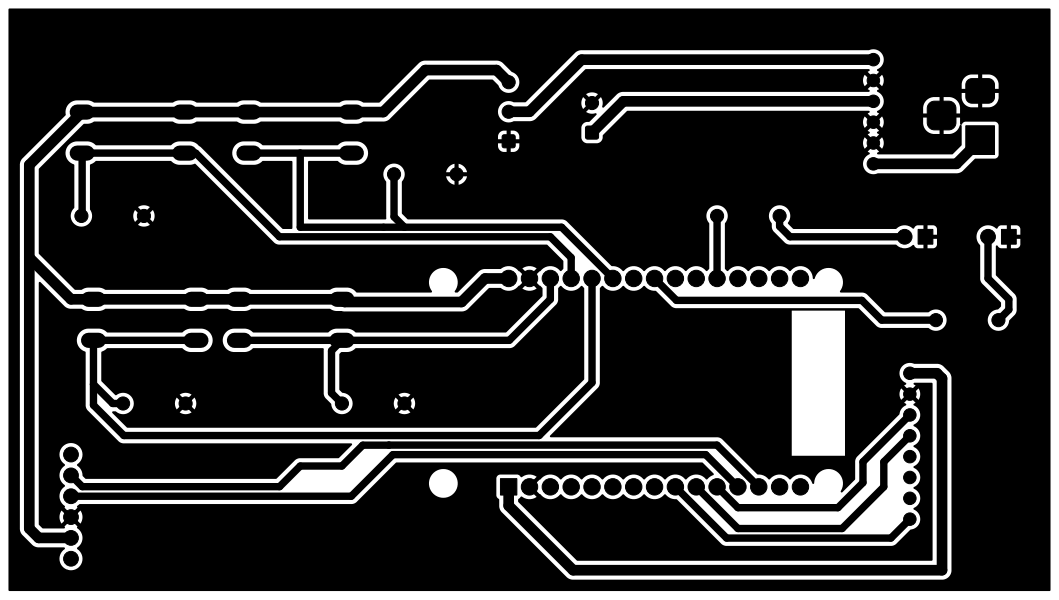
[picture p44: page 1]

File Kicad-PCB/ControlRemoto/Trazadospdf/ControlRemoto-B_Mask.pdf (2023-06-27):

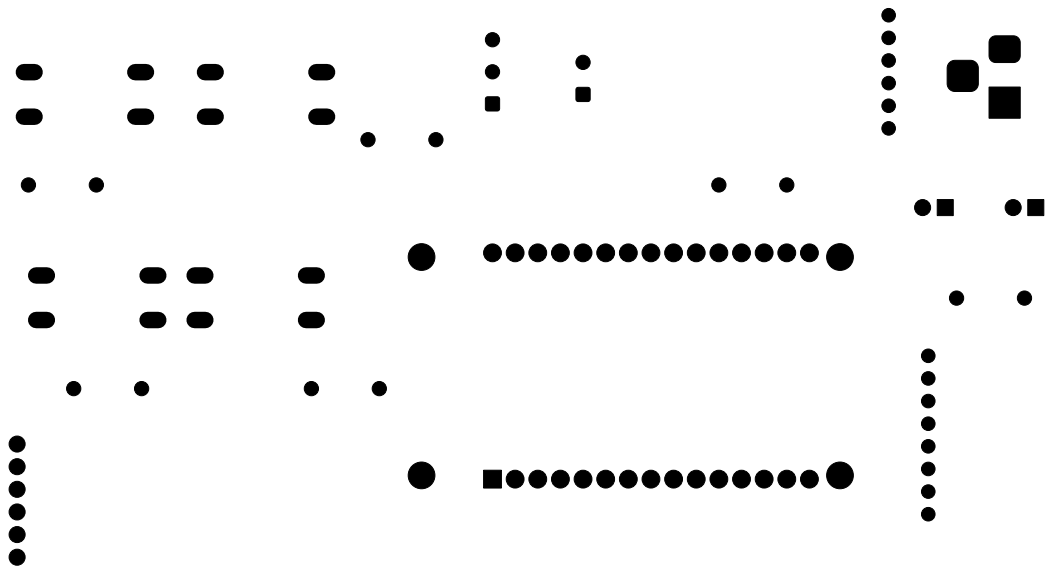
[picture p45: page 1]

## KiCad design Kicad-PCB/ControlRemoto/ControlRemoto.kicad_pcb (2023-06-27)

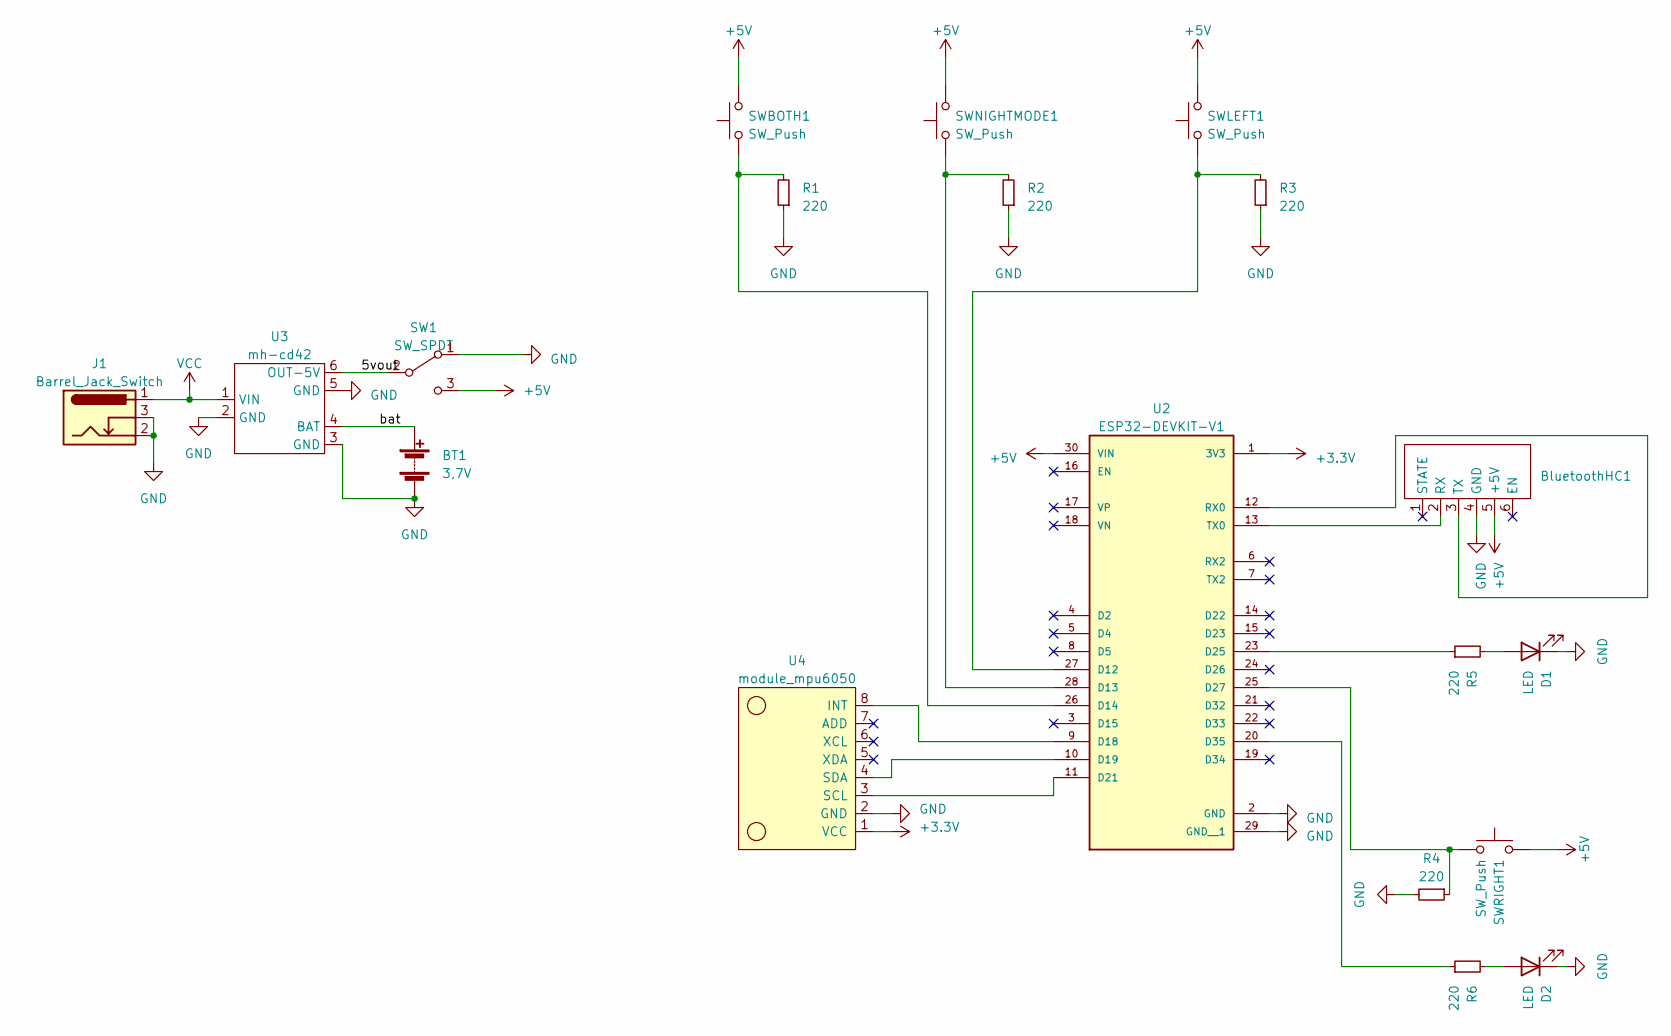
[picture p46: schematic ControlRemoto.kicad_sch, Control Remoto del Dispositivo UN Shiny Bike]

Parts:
BT1: 3,7V; SolderWire-0.1sqmm_1x02_P3.6mm_D0.4mm_OD1mm
BluetoothHC1: hc-05
D1, D2: LED; LED_D4.0mm
J1: Barrel_Jack_Switch; BarrelJack_Horizontal
R1, R2, R3, R4, R5, R6: 220; R_Axial_DIN0207_L6.3mm_D2.5mm_P7.62mm_Horizontal
SW1: SW_SPDT; SolderWire-0.1sqmm_1x03_P3.6mm_D0.4mm_OD1mm
SWBOTH1: SW_Push; SW_PUSH-12mm
SWLEFT1: SW_Push; SW_PUSH-12mm
SWNIGHTMODE1: SW_Push; SW_PUSH-12mm
SWRIGHT1: SW_Push; SW_PUSH-12mm
U2: ESP32-DEVKIT-V1; MODULE_ESP32_DEVKIT_V1; PARTREV N/A
U3: mh-cd42
U4: module_mpu6050

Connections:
+3.3V: U2.1 (3V3), U4.1 (VCC)
+5V: BluetoothHC1.5 (+5V), SW1.3 (C), SWBOTH1.2, SWLEFT1.2, SWNIGHTMODE1.2, SWRIGHT1.2, U2.30 (VIN)
/5vout: SW1.2 (B), U3.6 (OUT-5V)
/bat: BT1.1 (+), U3.4 (BAT)
GND: BT1.2 (-), BluetoothHC1.4 (GND), D1.1 (K), D2.1 (K), J1.2, J1.3, R1.1, R2.1, R3.1, R4.2, SW1.1 (A), U2.2 (GND), U2.29 (GND__1), U3.2 (GND), U3.3 (GND), U3.5 (GND), U4.2 (GND)
unnamed: BluetoothHC1.2 (RX), U2.13 (TX0)
unnamed: BluetoothHC1.3 (TX), U2.12 (RX0)
unnamed: D1.2 (A), R5.2
unnamed: D2.2 (A), R6.2
unnamed: R3.2, SWLEFT1.1, U2.27 (D12)
unnamed: R2.2, SWNIGHTMODE1.1, U2.28 (D13)
unnamed: R1.2, SWBOTH1.1, U2.26 (D14)
unnamed: U2.9 (D18), U4.8 (INT)
unnamed: U2.10 (D19), U4.4 (SDA)
unnamed: U2.11 (D21), U4.3 (SCL)
unnamed: R5.1, U2.23 (D25)
unnamed: R4.1, SWRIGHT1.1, U2.25 (D27)
unnamed: R6.1, U2.20 (D35)
VCC: J1.1, U3.1 (VIN)

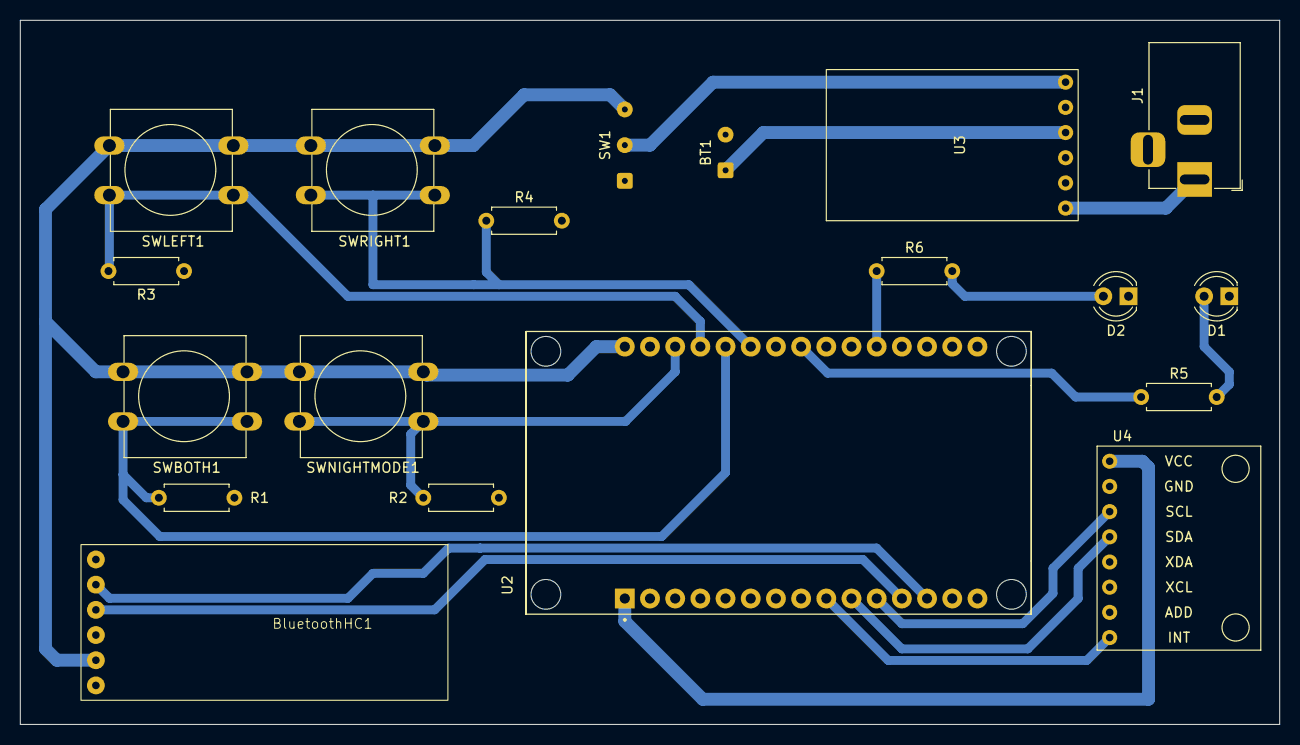
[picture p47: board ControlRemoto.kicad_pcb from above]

Board: 2 copper layers, 127.0 x 71.0 mm, 19 parts (0 on the bottom side), 19 nets.

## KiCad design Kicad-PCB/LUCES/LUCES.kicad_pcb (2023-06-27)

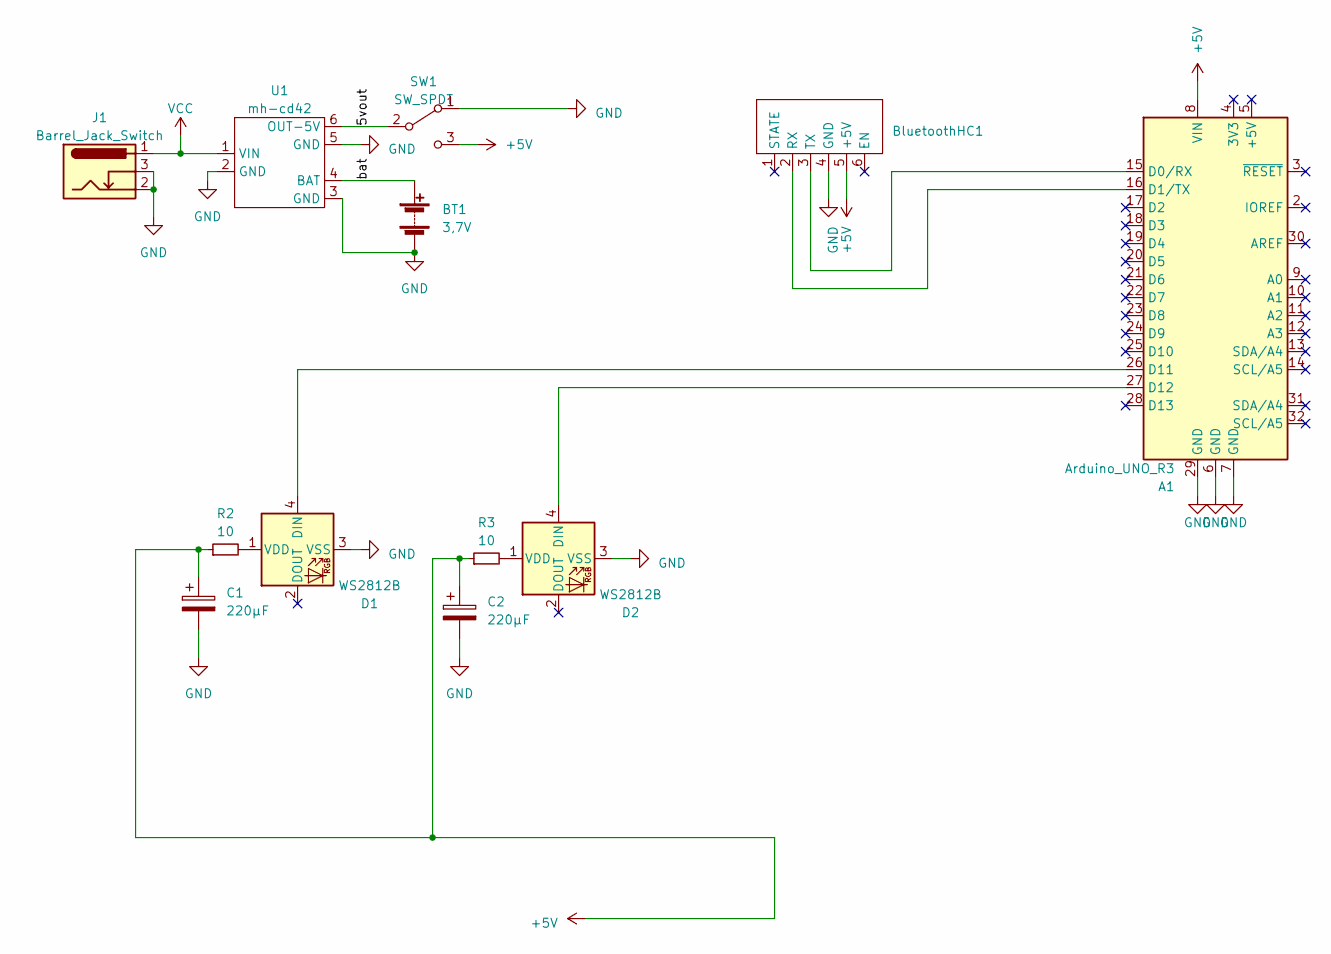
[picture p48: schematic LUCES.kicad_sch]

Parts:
A1: Arduino_UNO_R3
BT1: 3,7V; SolderWire-0.1sqmm_1x02_P3.6mm_D0.4mm_OD1mm
BluetoothHC1: hc-05
C1, C2: 220µF; CP_Radial_D5.0mm_P2.00mm
D1, D2: WS2812B; SolderWire-0.1sqmm_1x04_P3.6mm_D0.4mm_OD1mm
J1: Barrel_Jack_Switch; BarrelJack_Horizontal
R2, R3: 10; R_Axial_DIN0204_L3.6mm_D1.6mm_P5.08mm_Horizontal
SW1: SW_SPDT; SolderWire-0.1sqmm_1x03_P3.6mm_D0.4mm_OD1mm
U1: mh-cd42

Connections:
+5V: A1.8 (VIN), BluetoothHC1.5 (+5V), C1.1, C2.1, R2.1, R3.1, SW1.3 (C)
/5vout: SW1.2 (B), U1.6 (OUT-5V)
/bat: BT1.1 (+), U1.4 (BAT)
GND: A1.6 (GND), A1.7 (GND), A1.29 (GND), BT1.2 (-), BluetoothHC1.4 (GND), C1.2, C2.2, D1.3 (VSS), D2.3 (VSS), J1.2, J1.3, SW1.1 (A), U1.2 (GND), U1.3 (GND), U1.5 (GND)
unnamed: A1.15 (D0/RX), BluetoothHC1.3 (TX)
unnamed: A1.16 (D1/TX), BluetoothHC1.2 (RX)
unnamed: A1.26 (D11), D1.4 (DIN)
unnamed: A1.27 (D12), D2.4 (DIN)
unnamed: D1.1 (VDD), R2.2
unnamed: D2.1 (VDD), R3.2
VCC: J1.1, U1.1 (VIN)

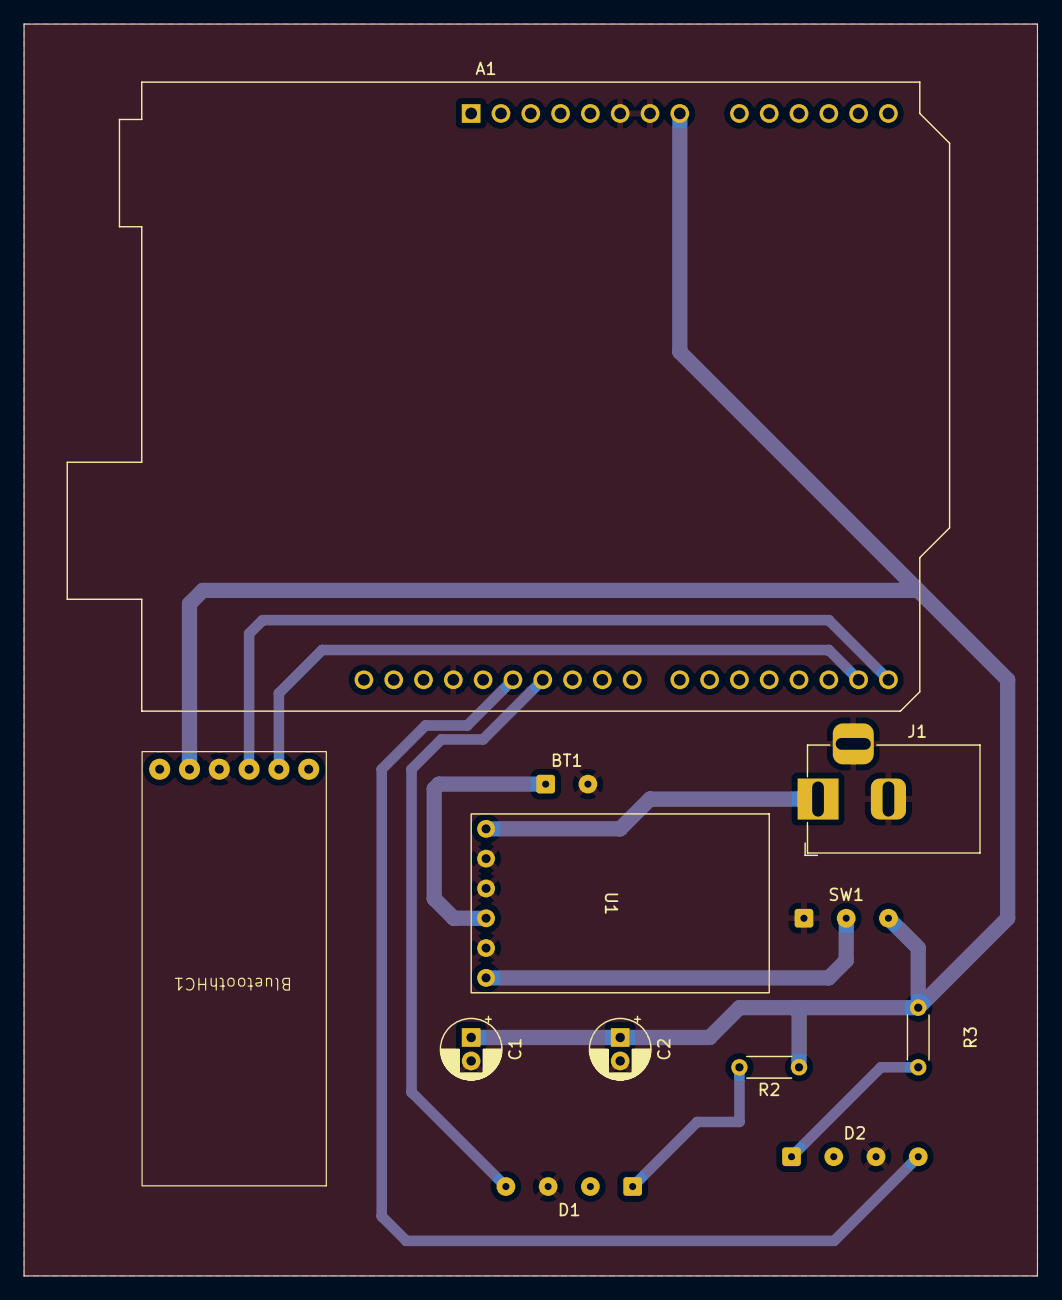
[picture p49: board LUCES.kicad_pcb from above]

Board: 2 copper layers, 86.4 x 106.7 mm, 12 parts (0 on the bottom side), 11 nets.

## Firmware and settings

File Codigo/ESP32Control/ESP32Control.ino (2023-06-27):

#include <Wire.h>

#define HC05_RX_PIN 3 // Pin RX del HC-05 conectado al pin 3 (GPIO3) del ESP32
#define HC05_TX_PIN 1 // Pin TX del HC-05 conectado al pin 1 (GPIO1) del ESP32
#define BUTTON_Right 27 // Pin del botón conectado al pin 12 (GPIO12) del ESP32
#define BUTTON_Left 12  //etc etc etc
#define BUTTON_Both 35
#define BUTTON_Night 34
#define LED_Right 32 
#define LED_Left 25

bool l = false;  //Asignacion de variables de control
bool r = false;
bool b = false;
unsigned long currentTime=0;
unsigned long previousTime=0;
int bp = 0;
bool button27 = false;
bool button12 = false;
bool button13 = false;
bool button14 = false; 

void setup() {
  Serial.begin(9600, SERIAL_8N1, HC05_RX_PIN, HC05_TX_PIN); // Inicia la comunicación serial con el HC-05
  pinMode(BUTTON_Right, INPUT_PULLUP); // Configura los pin de los botónes y leds como entrada como corresponda
  pinMode(BUTTON_Left, INPUT_PULLUP);
  pinMode(BUTTON_Both, INPUT_PULLUP);
  pinMode(BUTTON_Night, INPUT_PULLUP); 
  pinMode(LED_Right, OUTPUT);
  pinMode(LED_Left,OUTPUT);
}

void loop() {
  //Lectura
  button27 = digitalRead(BUTTON_Right);
  button12 = digitalRead(BUTTON_Left); // Lee el estado actual del botón
  button13 = digitalRead(BUTTON_Both);
  button14 = digitalRead(BUTTON_Night);

  //Modificacion de variables de control
  if (button27 == HIGH) {
    Serial.write(65);
    l = true;
    r = false;
    b = false;
  }
  if (button12 == HIGH) {
    Serial.write(66);
    r = true;  
    l = false;
    b = false;
  }
  if (button13 == HIGH) {
    Serial.write(67);
    delay(200);
    if(l == true || r == true || b == true){
      l = false; r = false; b = false;
    }else{
      b = true;
    }
  }
  if (button14 == HIGH) {
    Serial.write(68); 
  }


  //Decisiones
  if(r == true){
    digitalWrite(LED_Right,HIGH);
  }else{
    digitalWrite(LED_Right,LOW);
  }
  if(l == true){
    digitalWrite(LED_Left,HIGH);
  }else{
    digitalWrite(LED_Left,LOW);
  }
  if(b == true){
    currentTime = millis();
    if(bp == 0 && currentTime-previousTime > 1000){
      previousTime = currentTime;
      bp = 1;
    }else if(bp == 1 && currentTime-previousTime > 1000){
      previousTime = currentTime;
      bp = 0;
    }
    if(bp == 0){
      digitalWrite(LED_Right,HIGH);
      digitalWrite(LED_Left,HIGH);
    }
    if(bp == 1){
      digitalWrite(LED_Right,LOW);
      digitalWrite(LED_Left,LOW);
    }
  }
}


/*  
    #include <MPU6050.h>
    MPU6050 mpu;
  
  *En setup*

    Wire.begin();
    mpu.initialize();

  *Fuera de setup pero antes de loop*
    int16_t accelerometerXprev = mpu.getAccelerationX();
    int16_t accelerometerYprev = mpu.getAccelerationY();
    int16_t accelerometerZprev = mpu.getAccelerationZ();
    int16_t gyroscopeXprev = mpu.getRotationX();
    int16_t gyroscopeYprev = mpu.getRotationY();
    int16_t gyroscopeZprev = mpu.getRotationZ();

  *En loop*
    int16_t accelerometerX = mpu.getAccelerationX();
    int16_t accelerometerY = mpu.getAccelerationY();
    int16_t accelerometerZ = mpu.getAccelerationZ();
    int16_t gyroscopeX = mpu.getRotationX();
    int16_t gyroscopeY = mpu.getRotationY();
    int16_t gyroscopeZ = mpu.getRotationZ();

    if(accelerometerX < accelerometerXprev){
      ta frenando, aqui se prioriza prender todos los leds en rojo. Al dejar de frenar pasara al else 
    }else{
      //Codigo no documentado del loop

      Si r,l y b son falsos podemos entrar a utilizar la automatizacion del mpu6050
      if(r == false && l == false && b == false){
        if(gyroscopeX < -75){
          prender l
        }
        if(gyroscopeX > 75){
          prender r
        }
      }
    }

    Como se puede dar cuenta el mpu6050 debe calibrarse y puede ampliar sus funciones. Pero con que sepa cuando se frena
    o cuando se esta girando(sin dirrecionales) es suficiente por el momento.
    Tambien y es un poco obvio, al prender el led del controlador tambien se debe enviar el comando, el unico nuevo
    seria el del frendo, siendo Serial.write(69); :)
*/

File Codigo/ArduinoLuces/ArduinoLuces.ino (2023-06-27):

#include <Adafruit_NeoPixel.h>
#include <SoftwareSerial.h>    

#define LED_PIN 6
#define LED_PIN2 7
#define NUM_LEDS 1

Adafruit_NeoPixel strip(NUM_LEDS, LED_PIN, NEO_GRB + NEO_KHZ800); //Definimos la tira led, en nuestro caso una tira casera
Adafruit_NeoPixel strip2(NUM_LEDS, LED_PIN2, NEO_GRB + NEO_KHZ800); //Definimos la tira led, en nuestro caso una tira casera

SoftwareSerial miBT(10,11);    // Definimos los pines RX y TX del Arduino conectados al Bluetooth

bool mode = false; //Asignacion de variables de control
bool r = false;
bool l = false;
bool b = false;
int bp = 0;
unsigned long currentTime = 0;
unsigned long previousTime = 0;

void setup()
{
  Serial.begin(9600);   // Inicializamos  el puerto serie  
  Serial.println("listo");
  miBT.begin(9600);       // Inicializamos el puerto serie BT (Para Modo AT 2)velocidad= 38400
  strip.begin(); //Iniciamos las tiras led
  strip.show(); 
  strip2.begin();
  strip2.show(); 
}
 
void loop(){
  if(miBT.available()){    // Si llega un dato por el puerto BT se analiza y decide
      //Aqui se notara que el codigo es muy parecido al del Controlador :)
      char c = miBT.read();
      if(c == 'A' || c == 65){
        Serial.print(c);
        r = true;
        l = false;
        b = false;
      }
      if(c == 'B' || c == 66){
        Serial.print(c);
        l = true;
        r = false;
        b = false;
      }
      if(c == 'C' || c == 67){
        Serial.print(c);
        delay(200);
        if(l == true || r == true || b == true){
          l = false; r = false; b = false;
        }else{
          b = true;
        }
      }
      if(c == 'D' || c == 68){
        Serial.print(c);
        if(mode){mode = false;}else{mode = true;}
      }
  }
  if(mode == true){
      strip.setPixelColor(0, strip.Color(0, 0, 255));  
      strip2.setPixelColor(0, strip.Color(0, 0, 255));  
      if(l == true){
        strip2.setPixelColor(0, strip.Color(0, 255, 0));
        strip.setPixelColor(0, strip.Color(0, 0, 255));  
      }else{
        strip.setPixelColor(0, strip.Color(0, 0, 255));  
        strip2.setPixelColor(0, strip.Color(0, 0, 255));  
      }
      if(b == true){
        currentTime = millis();
        if(bp == 0 && currentTime-previousTime > 1000){
          previousTime = currentTime;
          bp = 1;
        }else if(bp == 1 && currentTime-previousTime > 1000){
          previousTime = currentTime;
          bp = 0;
        }
        if(bp == 0){
          strip.setPixelColor(0, strip.Color(0, 255, 0));
          strip2.setPixelColor(0, strip.Color(0, 255, 0));
        }
        if(bp == 1){
          strip.setPixelColor(0, strip.Color(0, 0, 255));  
          strip2.setPixelColor(0, strip.Color(0, 0, 255));
        }
      }

   }else{
      if(l == true){
        strip2.setPixelColor(0, strip.Color(0, 255, 0));
        strip.setPixelColor(0, strip.Color(0, 0, 0));  
      }else{
        strip.setPixelColor(0, strip.Color(0, 0, 0));  
        strip2.setPixelColor(0, strip.Color(0, 0, 0));  
      }
      if(b == true){
        currentTime = millis();
        if(bp == 0 && currentTime-previousTime > 1000){
          previousTime = currentTime;
          bp = 1;
        }else if(bp == 1 && currentTime-previousTime > 1000){
          previousTime = currentTime;
          bp = 0;
        }
        if(bp == 0){
          strip.setPixelColor(0, strip.Color(0, 255, 0));
          strip2.setPixelColor(0, strip.Color(0, 255, 0));
        }
        if(bp == 1){
          strip.setPixelColor(0, strip.Color(0, 0, 0));  
          strip2.setPixelColor(0, strip.Color(0, 0, 0));
        }
      }
   }
    if(r == true){
      strip.setPixelColor(0, strip.Color(0, 255, 0));  
    }else{
      if(b == false){
        if(mode == true){
          strip.setPixelColor(0, strip.Color(0, 0, 255)); 
        }else{
          strip.setPixelColor(0, strip.Color(0, 0, 0)); 
        }
      }
    }
    strip.show();
    strip2.show();
}


/*
  En la creacion de la tira led en el codigo es importante ver que uno puede determinar la cantidad de leds de la tira
  Esto es importante para diseños finales, donde podrian variar la cantidad de leds. Ademas de poder determinar individualmente
  el color. Por lo que por ejemplo, en la tira led que funcionaria como direccional izquierda podria mostrar un arcoiris.
  Tambien cabe mencionar que los ws2812b individuales son algo complicatos de soldar, por lo que muy probablemente se dañen
  las combinaciones de colores (como nos paso a nosotros), por lo que lo recomendable es que compren la cinta ya hecha. El codigo
  seria el mismo y podrian ampliar la gama de colores utilizados al modificar la funcion strip.Color(Red,Green,Blue)

  Dependiendo del diseño se pueden ampliar la cantidad de strip, pero el como se dejara a disposicion de la intuicion del lector

  Tal como en el comentario final del codigo del Control remoto, en loop existiria el if de freno y el else seria el resto de codigo
  Por lo cual lo extra aqui ya esta dicho.

  if(Serial.available())  // Si requiririamos enviar algun dato como retroalimentacion (como posible desconexiones o errores), usariamos este codigo
  {
     miBT.write(datos);
  }
  
*/
